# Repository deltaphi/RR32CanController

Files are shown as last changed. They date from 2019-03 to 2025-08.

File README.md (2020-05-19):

# RR32CanSwitchboard
Sketch for a Switchboard talking the Maerklin CAN protocol based on the ESP32 NodeMCU-Board.

## CI Status

* Linux Unittest Build


* Embedded Build


* Windows Unittest Build


## Software

This project is built using PlatformIO. It makes use of some features that may
not be easily portable to other Arduino-supported MCUs.

### Library Notes

This project makes use of several libraries. Versioned links to those libraries
are available as git submodules. Note that for seom libraries, using forks from
the same source as this project may be required.

Note that the CAN driver from the lib directory *must not* be present when you
want to compile using the ESP32-IDF driver. Otherwise, the Controller will just
attempt to sit there without sending queued messages or receiving any messages
transmitted on the bus.

### WiFi

This sketch only supports runtime-selection of CAN connection vs. WiFi
connection. The WiFi connection information (SSID, Password, IP of CAN-Gateway)
must be hardcoded.

To support hardcoding, a template file "_wificonfig.h" is provided. Copy the
template to "wificonfig.h" and adjust the configuration information to your
needs.

### Menuing

#### General concept

General: Shift + Direction Change enters the menu (cycles through menus) or leaves the menu without applying any changes.

Menu Levels:

* Level 0/Default: Loco Control
* Level 1: Loco List
* Level 2: Settings Menu

#### Menuing for Accessories

Menuing is required to map turnout input buttons to turnouts or action lists.

TODO: Design.

#### Menuing for Engine Control

Menuing is required for selecting an engine to control. This involves the following usecases:

* Select locally known engine
    * Show list of locally known Engines
    * Select engine
    * Selected Engine is now the active engine

* Select locally unknown engine
    * Verify that at least one local slot for an engine is open
    * If not:
        * Promt the user to remove an engine from the local database to be able to download a new one.
        * Show list of locally known Engines
        * Select an engine.
        * Selected Engine is marked for replacement
    * If yes:
        * Empty engine slot with lowest index is marked for replacement
    * Download list of Engines & total number of known engines from the master controller.
    * Either: Select engine from the master list
        * Details of Selected engine are downloaded.
    * Either: Scroll up/down beyond the currently known set of engine names.
        * If the engine name is unknown, download list of engines from the master controller.
    * Once the download is complete, the selected engine is now the active engine

#### Encoder Acceleration for Engine Control

Formula for acceleration curve: y = m*x + c. x is the time since the last rotation in the same direction,
y is the number of actual increments to apply.

The acceleration is linear. It should be set up so that there is a cutoff at 500ms (no acceleration when
increments are more than half a second apart) and that an "immediate" half rotation (e.g., within 50ms)
hits the opposite end of engine velocity.

Thus, boundary conditions for an encoder with 24 increments per rotaton are:
1 Tick = m*500ms + c
kMaxEngineVelocity Ticks / 12 increments = m * (50ms / 12 increments) + c

Formulas for calculating m and c:

m = (y1 - y2)/(x1 - x2) = (1 - (kMaxEngineVelocity/12))/(500 - (50/12)) = -0.16

c = y1 - m*x1 = 84.03

#### Settings Menu

Menu Entries:

* Turnout mapping
* Action list mapping
* Default connection settings
* WiFi settings

##### Turnout Mapping

When in the Turnout mapping menu:

* Press a button (red or green) for a turnout
* Display shows number of button and whether red or green was pressed (line 1)
* Display shows human-readable number of currently mapped turnout
* Use encoder to adjust the number of the turnout
* pressing the encoder stores the turnout mapping (visual feedback possible?)
* pressing another turnout button switches to settings for that button
* pressing shift + encoder leaves the menu.

Possible extension: Use the function buttons to increase/decrease in steps of 10

### Unit Testing

This project includes a CMake project.
The CMake project is purely used to run unit tests for some parts of the code on your development machine.
You do not need to deal with unit tests (or the CMake project) unless you want to actively develop the software.
To use the CMake project, create an out-of-tree build directoy (in-tree build will confuse the Automagic of PlatformIO).
Unit testing should be possible using any C++14 capable compiler on any Desktop Operating System.
It has been tested successefully using MSVC 2017 Community Edition.

## Hardware

### PCB

There is a KiCAD PCB design included for turning this project into a handheld device.
The PCB is designed for the [Strapubox 2090 case](https://www.reichelt.de/kunststoffgehaeuse-129-x-40-x-26-mm-sp-2090-sw-p33828.html?&trstct=pos_0).

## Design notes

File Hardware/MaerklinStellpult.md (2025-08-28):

# Abmessungen Maerklin Stellpult

## Grau

Katalogangabe: 40x80mm

## Blau

Gehäuse: 36,5mm x 70mm
Überstand Anschlüsse:
* Buchse Links 3,2mm
* Stift rechts 7,7mm
* Buchsen hinten 3,2mm

Größe über alles:
40 x 81,7mm

Mindestabstand der Gehäuse beim Stecken:
3,2mm + 1mm = 4,2mm - real nie erreicht!

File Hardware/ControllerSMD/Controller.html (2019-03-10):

# C:\Users\Damian\Documents\PlatformIO\Projects\esp32-can\Hardware\Controller\Controller.sch

09.03.2019 09:19:10

Eeschema (5.0.2)-1

Component Count:60

Ref | Qnty | Value | Part | Datasheet | Description | Vendor
C1, C2, C3, C4, C5, C6, C7, C8, C9, C10 | 10 | 10n | Device:C | ~ | Unpolarized capacitor
C11 | 1 | 100n | Device:C | ~ | Unpolarized capacitor
C12 | 1 | 470u | Device:CP | ~ | Polarized capacitor
C13 | 1 | 4u7 | Device:CP | ~ | Polarized capacitor
D1, D2, D3 | 3 | D_Schottky | Device:D_Schottky | ~ | Schottky diode
H1, H2 | 2 | Case Screw | Mechanical:MountingHole | ~ | Mounting Hole without connection
H3, H4, H5, H6 | 4 | PCB Screw | Mechanical:MountingHole_Pad | ~ | Mounting Hole with connection
J1 | 1 | 8P8C | Connector:8P8C | ~ | RJ connector, 8P8C (8 positions 8 connected), RJ31/RJ32/RJ33/RJ34/RJ35/RJ41/RJ45/RJ49/RJ61
J2 | 1 | LCD Header | Connector:Conn_01x04_Female | ~ | Generic connector, single row, 01x04, script generated (kicad-library-utils/schlib/autogen/connector/)
J3 | 1 | USB_B_Micro | Connector:USB_B_Micro | ~ | USB Micro Type B connector
J4 | 1 | S88 | Connector_Generic:Conn_01x06 | ~ | Generic connector, single row, 01x06, script generated (kicad-library-utils/schlib/autogen/connector/)
J5 | 1 | Screw_Terminal_01x05 | Connector:Screw_Terminal_01x05 | ~ | Generic screw terminal, single row, 01x05, script generated (kicad-library-utils/schlib/autogen/connector/)
R1, R2, R3, R4, R5, R6, R7, R8, R9, R10, R11, R12, R13, R14, R15, R16, R17, R18, R19, R20 | 20 | 10k | Device:R | ~ | Resistor
SW1 | 1 | Rotary_Encoder_Switch | Device:Rotary_Encoder_Switch | ~ | Rotary encoder, dual channel, incremental quadrate outputs, with switch
SW2 | 1 | SW_F0 | Switch:SW_Push | | Push button switch, generic, two pins
SW3 | 1 | SW_F1 | Switch:SW_Push | | Push button switch, generic, two pins
SW4 | 1 | SW_F2 | Switch:SW_Push | | Push button switch, generic, two pins
SW5 | 1 | SW_F3 | Switch:SW_Push | | Push button switch, generic, two pins
SW6 | 1 | SW_F4 | Switch:SW_Push | | Push button switch, generic, two pins
SW7 | 1 | Shift | Switch:SW_Push | | Push button switch, generic, two pins
SW8 | 1 | Stop | Switch:SW_Push | | Push button switch, generic, two pins
U1 | 1 | ESP32-WROOM-32 | RF_Module:ESP32-WROOM-32 | https://www.espressif.com/sites/default/files/documentation/esp32-wroom-32d_esp32-wroom-32u_datasheet_en.pdf | RF Module, ESP32-D0WDQ6 SoC, Wi-Fi 802.11b/g/n, Bluetooth, BLE, 32-bit, 2.7-3.6V, SMD
U2 | 1 | TJA1051T | Interface_CAN_LIN:TJA1051T | http://www.nxp.com/documents/data_sheet/TJA1051.pdf | High-Speed CAN Transceiver, silent mode, SOIC-8
U3 | 1 | 74LS367 | 74xx:74LS367 | http://www.ti.com/lit/gpn/sn74LS367 | Hex Bus Driver 3-state outputs
U4 | 1 | CH340C | Interface_USB:CH340G | http://www.datasheet5.com/pdf-local-2195953 | USB serial converter, UART, SOIC-16
U5 | 1 | XM1584 | ControllerParts:XM1584 | | XM1584 Switching Voltage Regulator Module

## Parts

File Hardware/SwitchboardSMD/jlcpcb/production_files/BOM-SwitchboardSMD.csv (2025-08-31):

Comment | Designator | Footprint | LCSC | Quantity
100k | R14,R15,R16,R17,R18,R19,R20,R21,R3 | R_1206_3216Metric_Pad1.30x1.75mm_HandSolder | C17900 | 9
10k | R1,R10,R11,R2,R4,R5,R6,R7,R8,R9 | R_1206_3216Metric_Pad1.30x1.75mm_HandSolder | C17902 | 10
10n | C1,C2,C3,C4,C5,C6,C7,C8 | C_1206_3216Metric | C1846 | 8
100n | C9 | C_1206_3216Metric | C24497 | 1
4014 | U3 | TSSOP-16_4.4x5mm_P0.65mm | C2877059 | 1
MMBT5551L | Q1 | SOT-23 | C41095 | 1
4044 | U1,U2 | TSSOP-16_4.4x5mm_P0.65mm | C74801 | 2
SW_Push | SW1 | SW_PUSH_6mm |  | 1
MountingHole_Pad | H1 | MountingHole_2.2mm_M2 |  | 1
MountingHole_Pad | H2 | MountingHole_2.2mm_M2 |  | 1
MountingHole_Pad | H3 | MountingHole_2.2mm_M2 |  | 1
MountingHole_Pad | H4 | MountingHole_2.2mm_M2 |  | 1
SW_Push | SW2 | SW_PUSH_6mm |  | 1
SW_Push | SW3 | SW_PUSH_6mm |  | 1
SW_Push | SW5 | SW_PUSH_6mm |  | 1
SW_Push | SW6 | SW_PUSH_6mm |  | 1
SW_Push | SW7 | SW_PUSH_6mm |  | 1
SW_Push | SW8 | SW_PUSH_6mm |  | 1
SW_Push | SW4 | SW_PUSH_6mm |  | 1
S88_In | J2 | PinSocket_1x06_P2.54mm_Horizontal |  | 1
S88_Out | J4 | PinHeader_1x06_P2.54mm_Horizontal |  | 1
MountingHole_Pad | H5 | MountingHole_3.2mm_M3_Pad_Via |  | 1

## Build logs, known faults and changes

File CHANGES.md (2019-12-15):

# ChangeLog

## Version 1.1

* Add serial console.
  * Switch turnouts not accessible via button.
  * Store and execute Accessory Action Lists.

## Version 1.0

This version is the first general-purpose release. Every release before this
was geared towards a specific prototypical setup.

* Support WiFi and CAN connection.
* Support configurable Turnouts.

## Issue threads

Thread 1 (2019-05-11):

RX/TX lines are swapped

deltaphi, 2019-05-11:
The RX and TX lines in the PCD design are swapped, at least in f3e92ce8fdfd0f38a7215b2d083cc8cbbf3de2ce

Correct is:

* TXD0/IO1/Pin 35 of the ESP32WROOM must be connected to RXD/Pin3 of the CH340C
* PXD0/IO3/Pin 34 of the ESP32WROOM must be connected to TXD/Pin2 of the CH340C

Closed 2019-05-19.

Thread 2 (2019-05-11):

Auto-Reset circuit not working

deltaphi, 2019-05-11:
The Auto-Reset Circuit itself is working. However:

* There should be 10k pullups on GPIO0 an EN.
* The Auto-Reset Circuit does not guard against serial software asserting both RTS and DTR.

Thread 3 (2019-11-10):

Acceleration values questionable

deltaphi, 2019-11-10:
The computed acceleration values do not appear to be correct. Also, the acceleration is somewhat unintuitive, as the uC appears to be loosing encoder ticks on very fast rotations.

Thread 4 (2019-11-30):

All turnouts switched on startup

deltaphi, 2019-11-30:
When the ESP32 is starting, it immediately generates button presses for all turnouts.

Reason is likely the inverted logic of the S88 bus.

Closed 2019-11-30.

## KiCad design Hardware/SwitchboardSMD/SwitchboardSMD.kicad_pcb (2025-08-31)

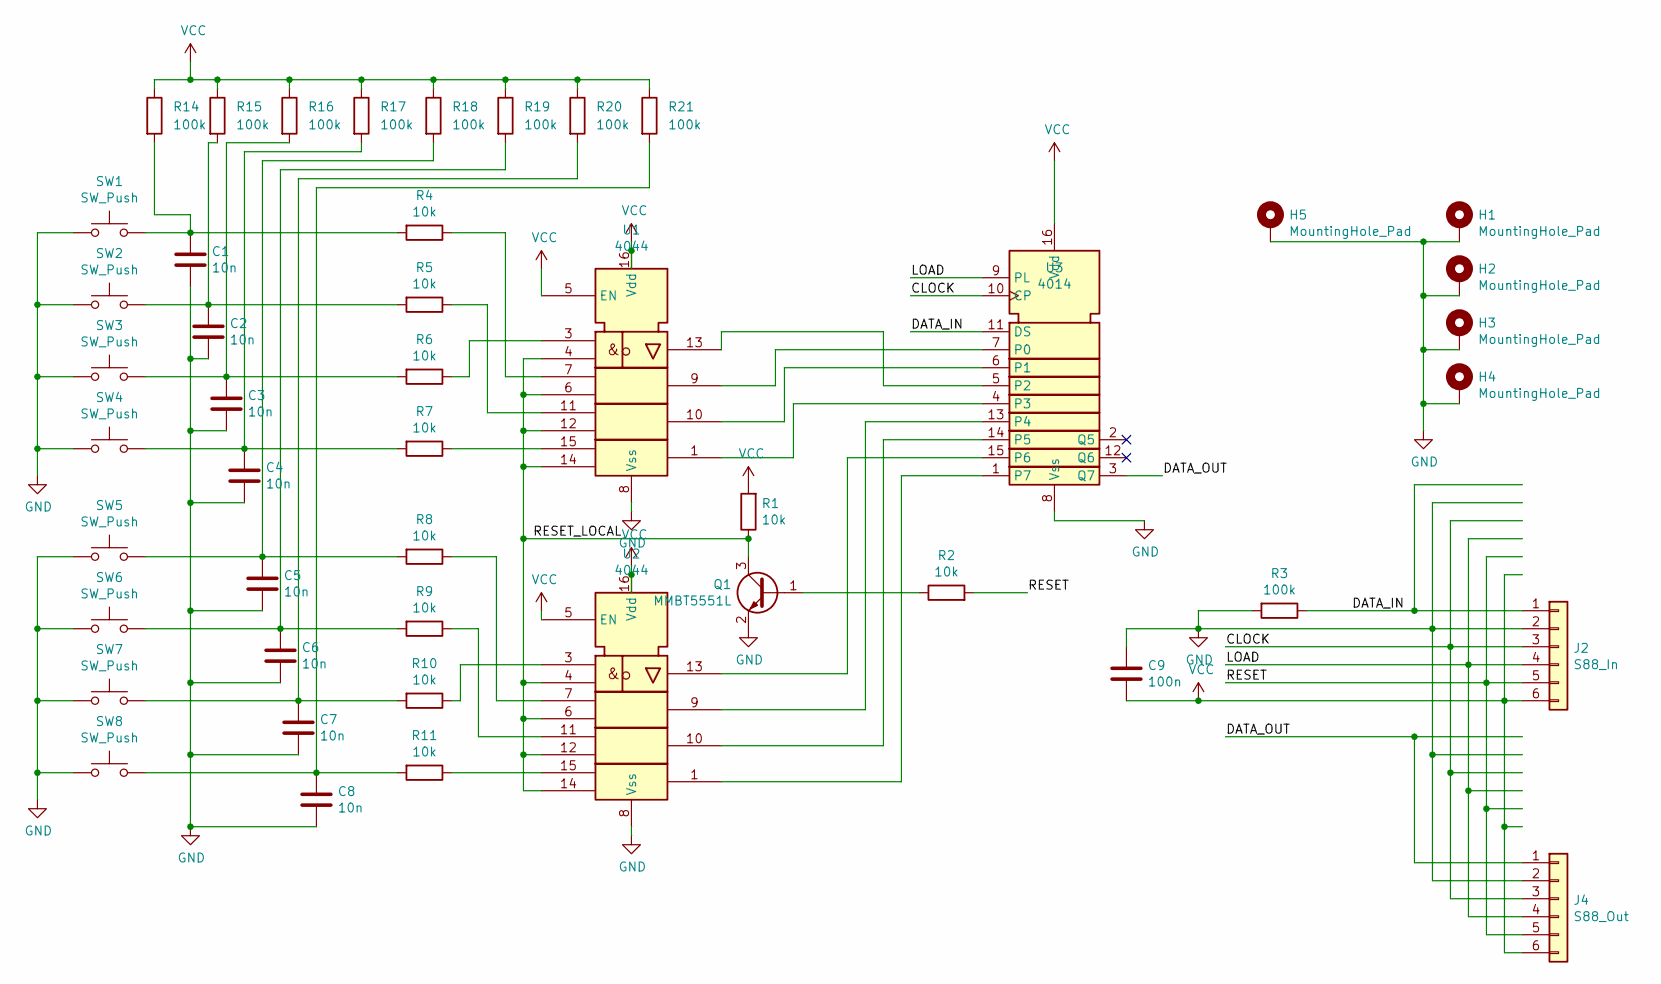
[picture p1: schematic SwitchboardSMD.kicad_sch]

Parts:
C1, C2, C3, C4, C5, C6, C7, C8: 10n; C_1206_3216Metric
C9: 100n; C_1206_3216Metric
H1, H2, H3, H4: MountingHole_Pad; MountingHole_2.2mm_M2
H5: MountingHole_Pad; MountingHole_3.2mm_M3_Pad_Via
J2: S88_In; PinSocket_1x06_P2.54mm_Horizontal
J4: S88_Out; PinHeader_1x06_P2.54mm_Horizontal
Q1: MMBT5551L; SOT-23
R1, R2, R4, R5, R6, R7, R8, R9, R10, R11: 10k; R_1206_3216Metric_Pad1.30x1.75mm_HandSolder
R3, R14, R15, R16, R17, R18, R19, R20, R21: 100k; R_1206_3216Metric_Pad1.30x1.75mm_HandSolder
SW1, SW2, SW3, SW4, SW5, SW6, SW7, SW8: SW_Push; SW_PUSH_6mm
U1, U2: 4044; TSSOP-16_4.4x5mm_P0.65mm
U3: 4014; TSSOP-16_4.4x5mm_P0.65mm

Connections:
/CLOCK: J2.3, J4.3, U3.10 (CP)
/DATA_IN: J2.1, R3.1, U3.11 (DS)
/DATA_OUT: J4.1, U3.3 (Q7)
/LOAD: J2.4, J4.4, U3.9 (PL)
/RESET: J2.5, J4.5, R2.2
/RESET_LOCAL: Q1.3 (C), R1.1, U1.4, U1.6, U1.12, U1.14, U2.4, U2.6, U2.12, U2.14
GND: C1.2, C2.2, C3.2, C4.2, C5.2, C6.2, C7.2, C8.2, C9.1, H1.1, H2.1, H3.1, H4.1, H5.1, J2.2, J4.2, Q1.2 (E), R3.2, SW1.1, SW2.1, SW3.1, SW4.1, SW5.1, SW6.1, SW7.1, SW8.1, U1.8 (Vss), U2.8 (Vss), U3.8 (Vss)
unnamed: C1.1, R4.2, R14.2, SW1.2
unnamed: C2.1, R5.2, R15.2, SW2.2
unnamed: C3.1, R6.2, R16.2, SW3.2
unnamed: C4.1, R7.2, R17.2, SW4.2
unnamed: C5.1, R8.2, R18.2, SW5.2
unnamed: C6.1, R9.2, R19.2, SW6.2
unnamed: C7.1, R10.2, R20.2, SW7.2
unnamed: C8.1, R11.2, R21.2, SW8.2
unnamed: Q1.1 (B), R2.1
unnamed: R4.1, U1.7
unnamed: R5.1, U1.11
unnamed: R6.1, U1.3
unnamed: R7.1, U1.15
unnamed: R8.1, U2.7
unnamed: R9.1, U2.11
unnamed: R10.1, U2.3
unnamed: R11.1, U2.15
unnamed: U1.9, U3.7 (P0)
unnamed: U1.10, U3.6 (P1)
unnamed: U1.13, U3.5 (P2)
unnamed: U1.1, U3.4 (P3)
unnamed: U2.9, U3.13 (P4)
unnamed: U2.10, U3.14 (P5)
unnamed: U2.13, U3.15 (P6)
unnamed: U2.1, U3.1 (P7)
VCC: C9.2, J2.6, J4.6, R1.2, R14.1, R15.1, R16.1, R17.1, R18.1, R19.1, R20.1, R21.1, U1.5 (EN), U1.16 (Vdd), U2.5 (EN), U2.16 (Vdd), U3.16 (Vdd)

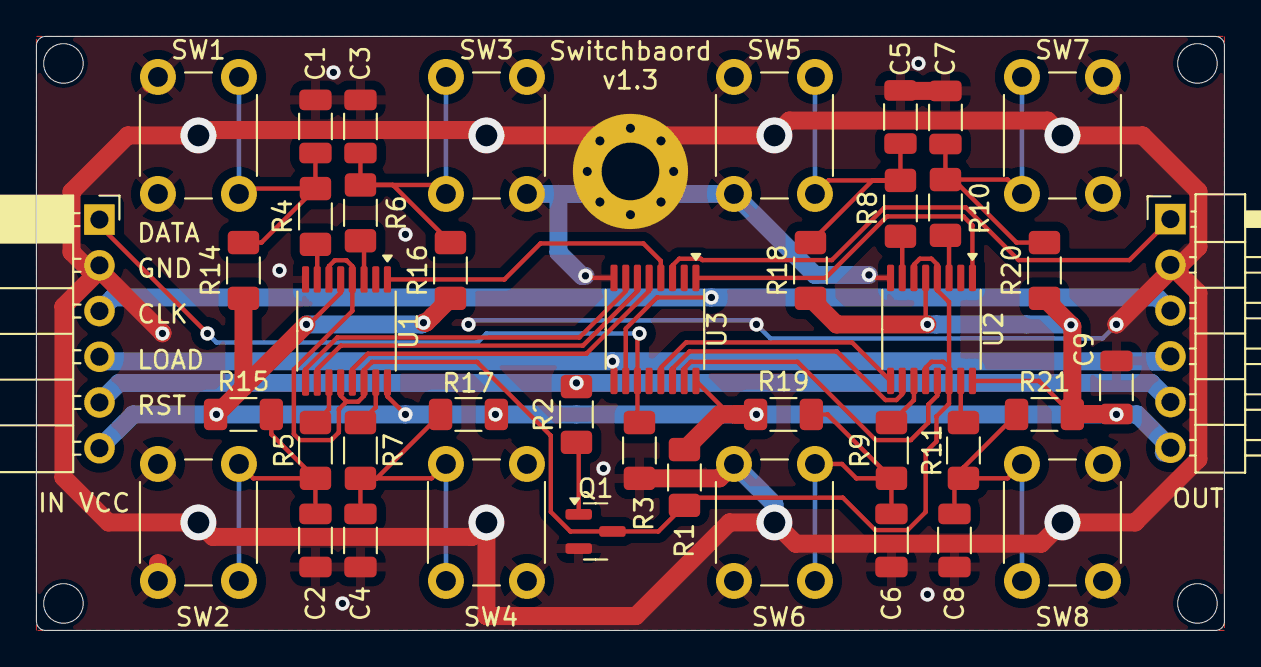
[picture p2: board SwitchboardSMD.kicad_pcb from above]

Board: 2 copper layers, 66.0 x 33.0 mm, 47 parts (0 on the bottom side), 33 nets.

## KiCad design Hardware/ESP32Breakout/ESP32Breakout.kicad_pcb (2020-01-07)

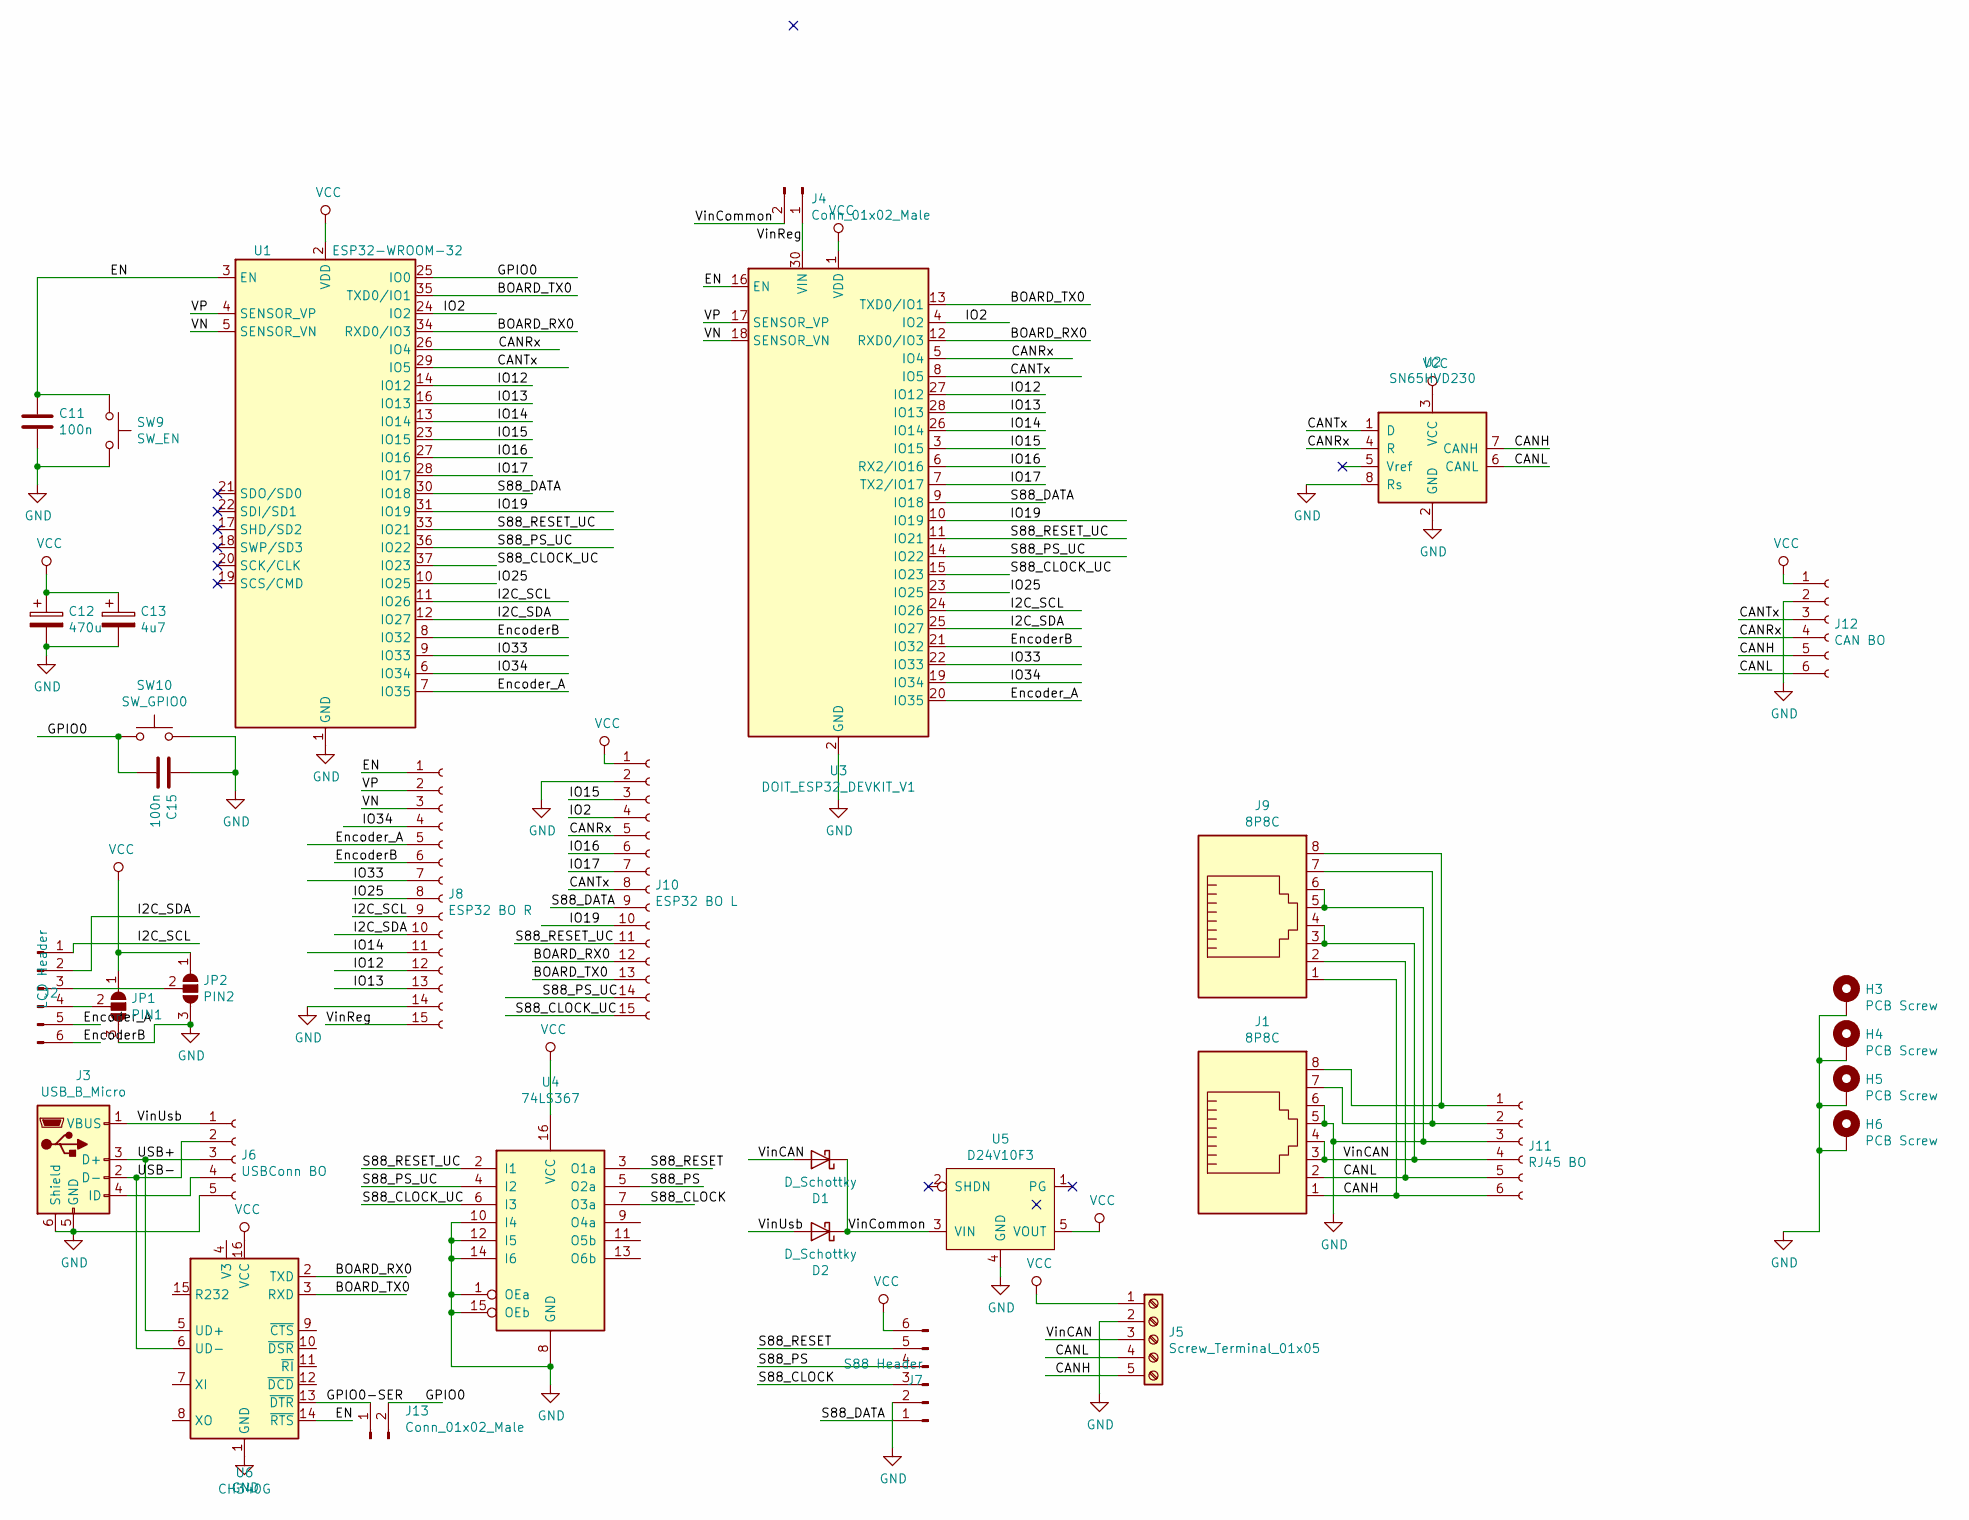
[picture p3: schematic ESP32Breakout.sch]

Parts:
C11, C15: 100n; C_Disc_D3.4mm_W2.1mm_P2.50mm
C12: 470u; CP_Radial_D10.0mm_P5.00mm
C13: 4u7; CP_Radial_D5.0mm_P2.50mm
D1, D2: D_Schottky; D_A-405_P7.62mm_Horizontal
H3, H4, H5, H6: PCB Screw; MountingHole_3.2mm_M3_Pad_Via
J1, J9: 8P8C; RJ45_Amphenol_54602-x08_Horizontal
J2: LCD Header; PinHeader_1x06_P2.54mm_Vertical
J3: USB_B_Micro; USB_Micro-B_Molex_47346-0001
J4, J13: Conn_01x02_Male; PinHeader_1x02_P2.54mm_Vertical
J5: Screw_Terminal_01x05; TerminalBlock_4Ucon_1x05_P3.50mm_Vertical
J6: USBConn BO; PinHeader_1x05_P2.54mm_Vertical
J7: S88 Header; PinHeader_1x06_P2.54mm_Vertical
J8: ESP32 BO R; PinHeader_1x15_P2.54mm_Vertical
J10: ESP32 BO L; PinHeader_1x15_P2.54mm_Vertical
J11: RJ45 BO; PinHeader_1x06_P2.54mm_Vertical
J12: CAN BO; PinHeader_1x06_P2.54mm_Vertical
JP1: PIN1; SolderJumper-3_P1.3mm_Open_Pad1.0x1.5mm_NumberLabels
JP2: PIN2; SolderJumper-3_P1.3mm_Open_Pad1.0x1.5mm_NumberLabels
SW9: SW_EN; SW_PUSH_6mm
SW10: SW_GPIO0; SW_PUSH_6mm
U1: ESP32-WROOM-32
U2: SN65HVD230; SOIC-8_3.9x4.9mm_P1.27mm
U3: DOIT_ESP32_DEVKIT_V1; ESP32-DEVKITV1
U4: 74LS367; SOP-16_4.55x10.3mm_P1.27mm
U5: D24V10F3
U6: CH340G; SOIC-16_3.9x9.9mm_P1.27mm

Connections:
/BOARD_RX0: J10.12, U1.34 (RXD0/IO3), U3.12 (RXD0/IO3), U6.2 (TXD)
/BOARD_TX0: J10.13, U1.35 (TXD0/IO1), U3.13 (TXD0/IO1), U6.3 (RXD)
/CANH: J1.1, J5.5, J9.1, J11.6, J12.5, U2.7 (CANH)
/CANL: J1.2, J5.4, J9.2, J11.5, J12.6, U2.6 (CANL)
/CANRx: J10.5, J12.4, U1.26 (IO4), U2.4 (R), U3.5 (IO4)
/CANTx: J10.8, J12.3, U1.29 (IO5), U2.1 (D), U3.8 (IO5)
/EN: C11.1, J8.1, SW9.1, U1.3 (EN), U3.16 (EN), U6.14 (~RTS)
/EncoderB: J2.6, J8.6, U1.8 (IO32), U3.21 (IO32)
/Encoder_A: J2.5, J8.5, U1.7 (IO35), U3.20 (IO35)
/GPIO0: C15.2, J13.2, SW10.1, U1.25 (IO0)
/GPIO0-SER: J13.1, U6.13 (~DTR)
/I2C_SCL: J2.1, J8.9, U1.11 (IO26), U3.24 (IO26)
/I2C_SDA: J2.2, J8.10, U1.12 (IO27), U3.25 (IO27)
/IO2: J10.4, U1.24 (IO2), U3.4 (IO2)
/IO12: J8.12, U1.14 (IO12), U3.27 (IO12)
/IO13: J8.13, U1.16 (IO13), U3.28 (IO13)
/IO14: J8.11, U1.13 (IO14), U3.26 (IO14)
/IO15: J10.3, U1.23 (IO15), U3.3 (IO15)
/IO16: J10.6, U1.27 (IO16), U3.6 (RX2/IO16)
/IO17: J10.7, U1.28 (IO17), U3.7 (TX2/IO17)
/IO19: J10.10, U1.31 (IO19), U3.10 (IO19)
/IO25: J8.8, U1.10 (IO25), U3.23 (IO25)
/IO33: J8.7, U1.9 (IO33), U3.22 (IO33)
/IO34: J8.4, U1.6 (IO34), U3.19 (IO34)
/S88_CLOCK: J7.3, U4.7 (O3a)
/S88_CLOCK_UC: J10.15, U1.37 (IO23), U3.15 (IO23), U4.6 (I3)
/S88_DATA: J7.1, J10.9, U1.30 (IO18), U3.9 (IO18)
/S88_PS: J7.4, U4.5 (O2a)
/S88_PS_UC: J10.14, U1.36 (IO22), U3.14 (IO22), U4.4 (I2)
/S88_RESET: J7.5, U4.3 (O1a)
/S88_RESET_UC: J10.11, U1.33 (IO21), U3.11 (IO21), U4.2 (I1)
/USB+: J3.3 (D+), J6.3, U6.5 (UD+)
/USB-: J3.2 (D-), J6.2, U6.6 (UD-)
/VN: J8.3, U1.5 (SENSOR_VN), U3.18 (SENSOR_VN)
/VP: J8.2, U1.4 (SENSOR_VP), U3.17 (SENSOR_VP)
/VinCAN: D1.2 (A), J1.3, J1.4, J5.3, J9.3, J9.4, J11.4
/VinCommon: D1.1 (K), D2.1 (K), J4.2, U5.3 (VIN)
/VinReg: J4.1, J8.15, U3.30 (VIN)
/VinUsb: D2.2 (A), J3.1 (VBUS), J6.1
GND: C11.2, C12.2, C13.2, C15.1, H3.1, H4.1, H5.1, H6.1, J1.5, J1.6, J3.5 (GND), J3.6 (Shield), J5.2, J6.5, J7.2, J8.14, J9.5, J9.6, J10.2, J11.3, J12.2, JP1.3 (B), JP2.3 (B), SW9.2, SW10.2, U1.1 (GND), U1.15 (GND), U1.38 (GND), U2.2 (GND), U2.8 (Rs), U3.2 (GND), U3.29 (GND), U4.1 (OEa), U4.8 (GND), U4.10 (I4), U4.12 (I5), U4.14 (I6), U4.15 (OEb), U5.4 (GND), U6.1 (GND)
unnamed: J1.7, J9.7, J11.2
unnamed: J1.8, J9.8, J11.1
unnamed: J2.3, JP2.2 (C)
unnamed: J2.4, JP1.2 (C)
unnamed: J3.4 (ID), J6.4
VCC: C12.1, C13.1, J5.1, J7.6, J10.1, J12.1, JP1.1 (A), JP2.1 (A), U1.2 (VDD), U2.3 (VCC), U3.1 (VDD), U4.16 (VCC), U5.5 (VOUT), U6.16 (VCC)

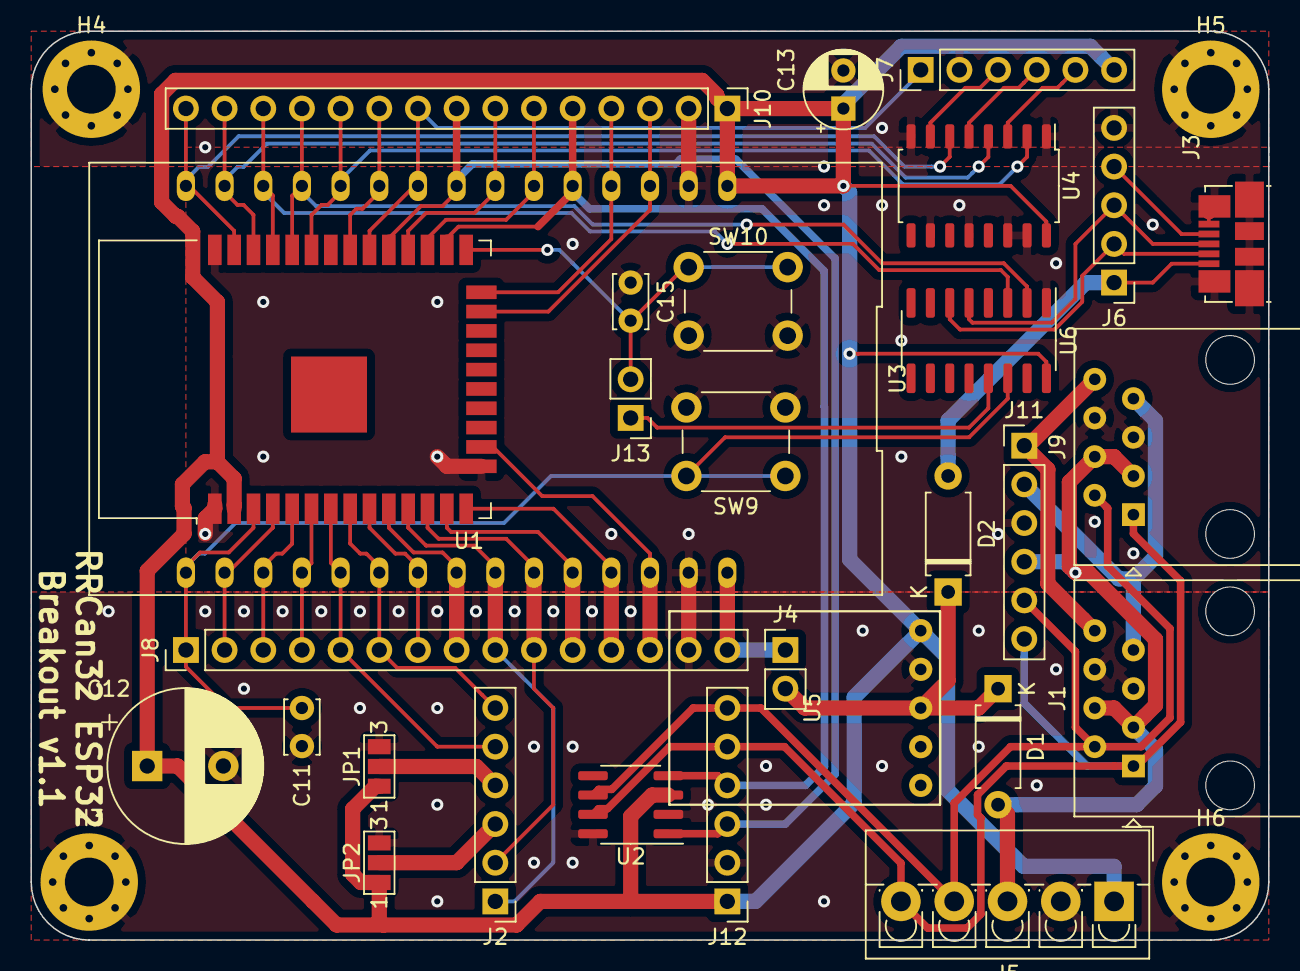
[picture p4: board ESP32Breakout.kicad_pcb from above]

Board: 2 copper layers, 81.3 x 59.7 mm, 33 parts (0 on the bottom side), 46 nets.

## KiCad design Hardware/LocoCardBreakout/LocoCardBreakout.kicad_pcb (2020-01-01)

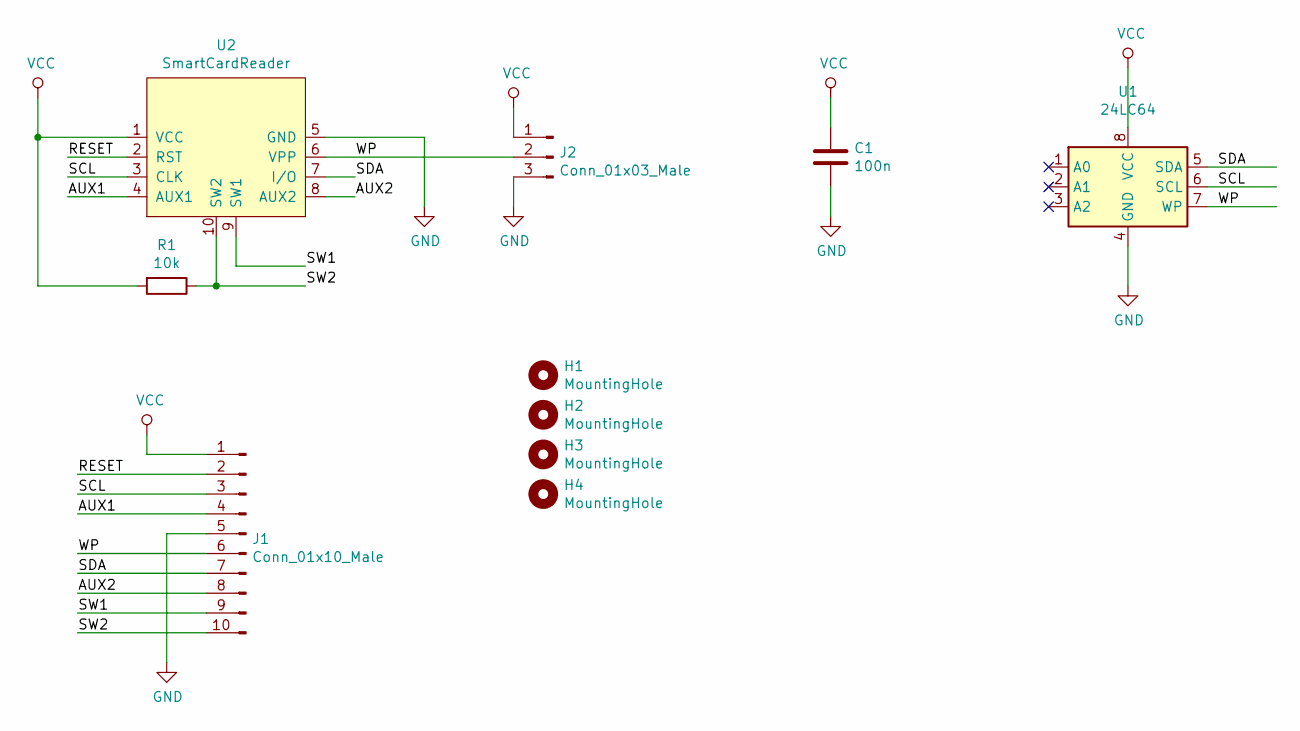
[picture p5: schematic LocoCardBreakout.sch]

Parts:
C1: 100n; C_Disc_D3.0mm_W1.6mm_P2.50mm
H1, H2, H3, H4: MountingHole; MountingHole_2.5mm
J1: Conn_01x10_Male; PinHeader_1x10_P2.54mm_Vertical
J2: Conn_01x03_Male; PinHeader_1x03_P2.54mm_Vertical
R1: 10k; R_Axial_DIN0207_L6.3mm_D2.5mm_P7.62mm_Horizontal
U1: 24LC64; DIP-8_W7.62mm_LongPads
U2: SmartCardReader

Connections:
/AUX1: J1.4, U2.4 (AUX1)
/AUX2: J1.8, U2.8 (AUX2)
/RESET: J1.2, U2.2 (RST)
/SCL: J1.3, U1.6 (SCL), U2.3 (CLK)
/SDA: J1.7, U1.5 (SDA), U2.7 (I/O)
/SW1: J1.9, U2.9 (SW1)
/SW2: J1.10, R1.1, U2.10 (SW2)
/WP: J1.6, J2.2, U1.7 (WP), U2.6 (VPP)
GND: C1.2, J1.5, J2.3, U1.4 (GND), U2.5 (GND)
VCC: C1.1, J1.1, J2.1, R1.2, U1.8 (VCC), U2.1 (VCC)

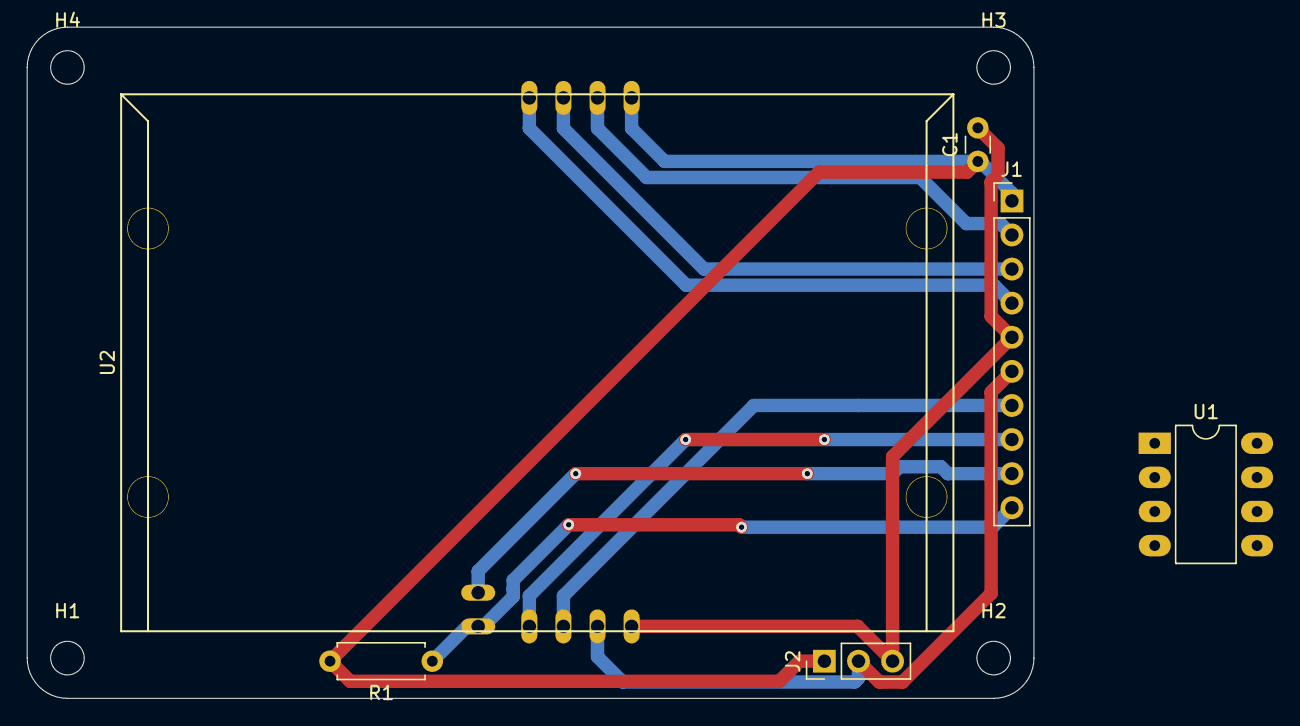
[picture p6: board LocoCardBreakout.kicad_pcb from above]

Board: 2 copper layers, 75.0 x 50.0 mm, 10 parts (0 on the bottom side), 10 nets.

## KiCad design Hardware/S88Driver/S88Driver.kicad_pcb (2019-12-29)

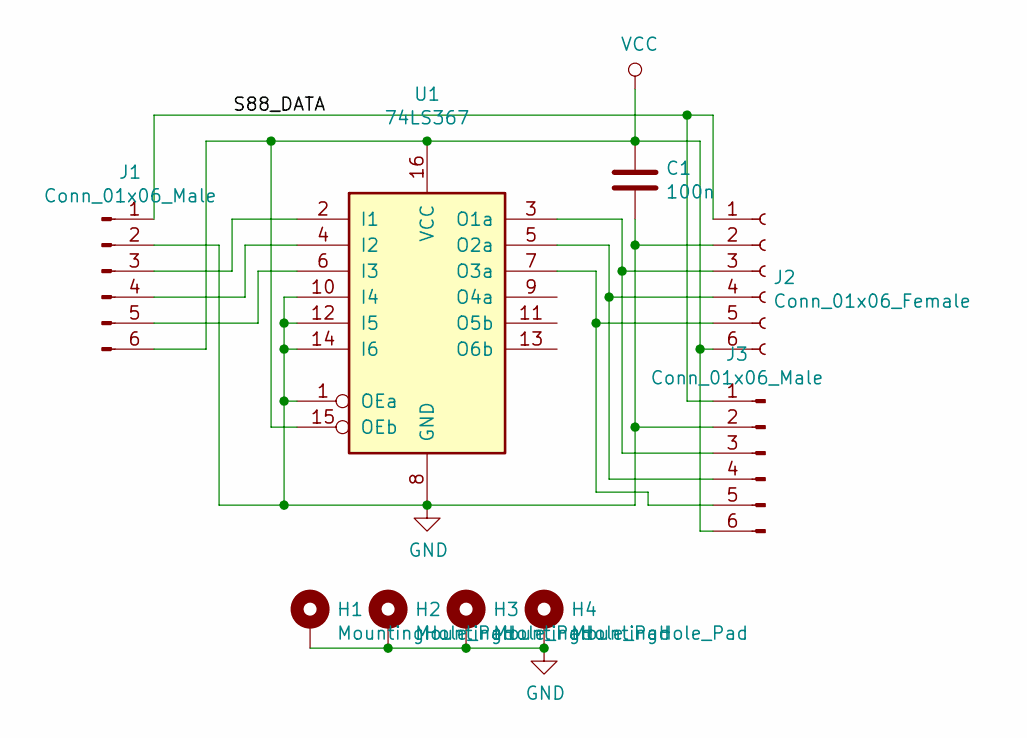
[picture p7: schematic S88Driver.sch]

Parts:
C1: 100n; C_Disc_D3.0mm_W1.6mm_P2.50mm
H1, H2, H3, H4: MountingHole_Pad; MountingHole_2.7mm_M2.5_Pad_Via
J1, J3: Conn_01x06_Male; PinSocket_1x06_P2.54mm_Vertical
J2: Conn_01x06_Female; PinSocket_1x06_P2.54mm_Horizontal
U1: 74LS367; DIP-16_W7.62mm_LongPads

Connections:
/S88_DATA: J1.1, J2.1, J3.1
GND: C1.2, H1.1, H2.1, H3.1, H4.1, J1.2, J2.2, J3.2, U1.1 (OEa), U1.8 (GND), U1.10 (I4), U1.12 (I5), U1.14 (I6)
unnamed: J1.3, U1.2 (I1)
unnamed: J1.4, U1.4 (I2)
unnamed: J1.5, U1.6 (I3)
unnamed: J2.3, J3.3, U1.3 (O1a)
unnamed: J2.4, J3.4, U1.5 (O2a)
unnamed: J2.5, J3.5, U1.7 (O3a)
VCC: C1.1, J1.6, J2.6, J3.6, U1.15 (OEb), U1.16 (VCC)

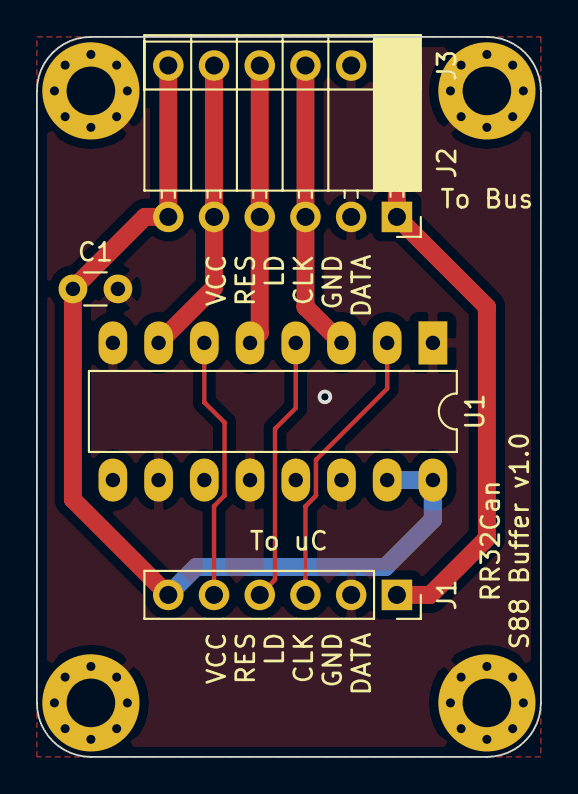
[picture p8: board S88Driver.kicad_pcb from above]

Board: 2 copper layers, 28.0 x 40.0 mm, 9 parts (0 on the bottom side), 9 nets.

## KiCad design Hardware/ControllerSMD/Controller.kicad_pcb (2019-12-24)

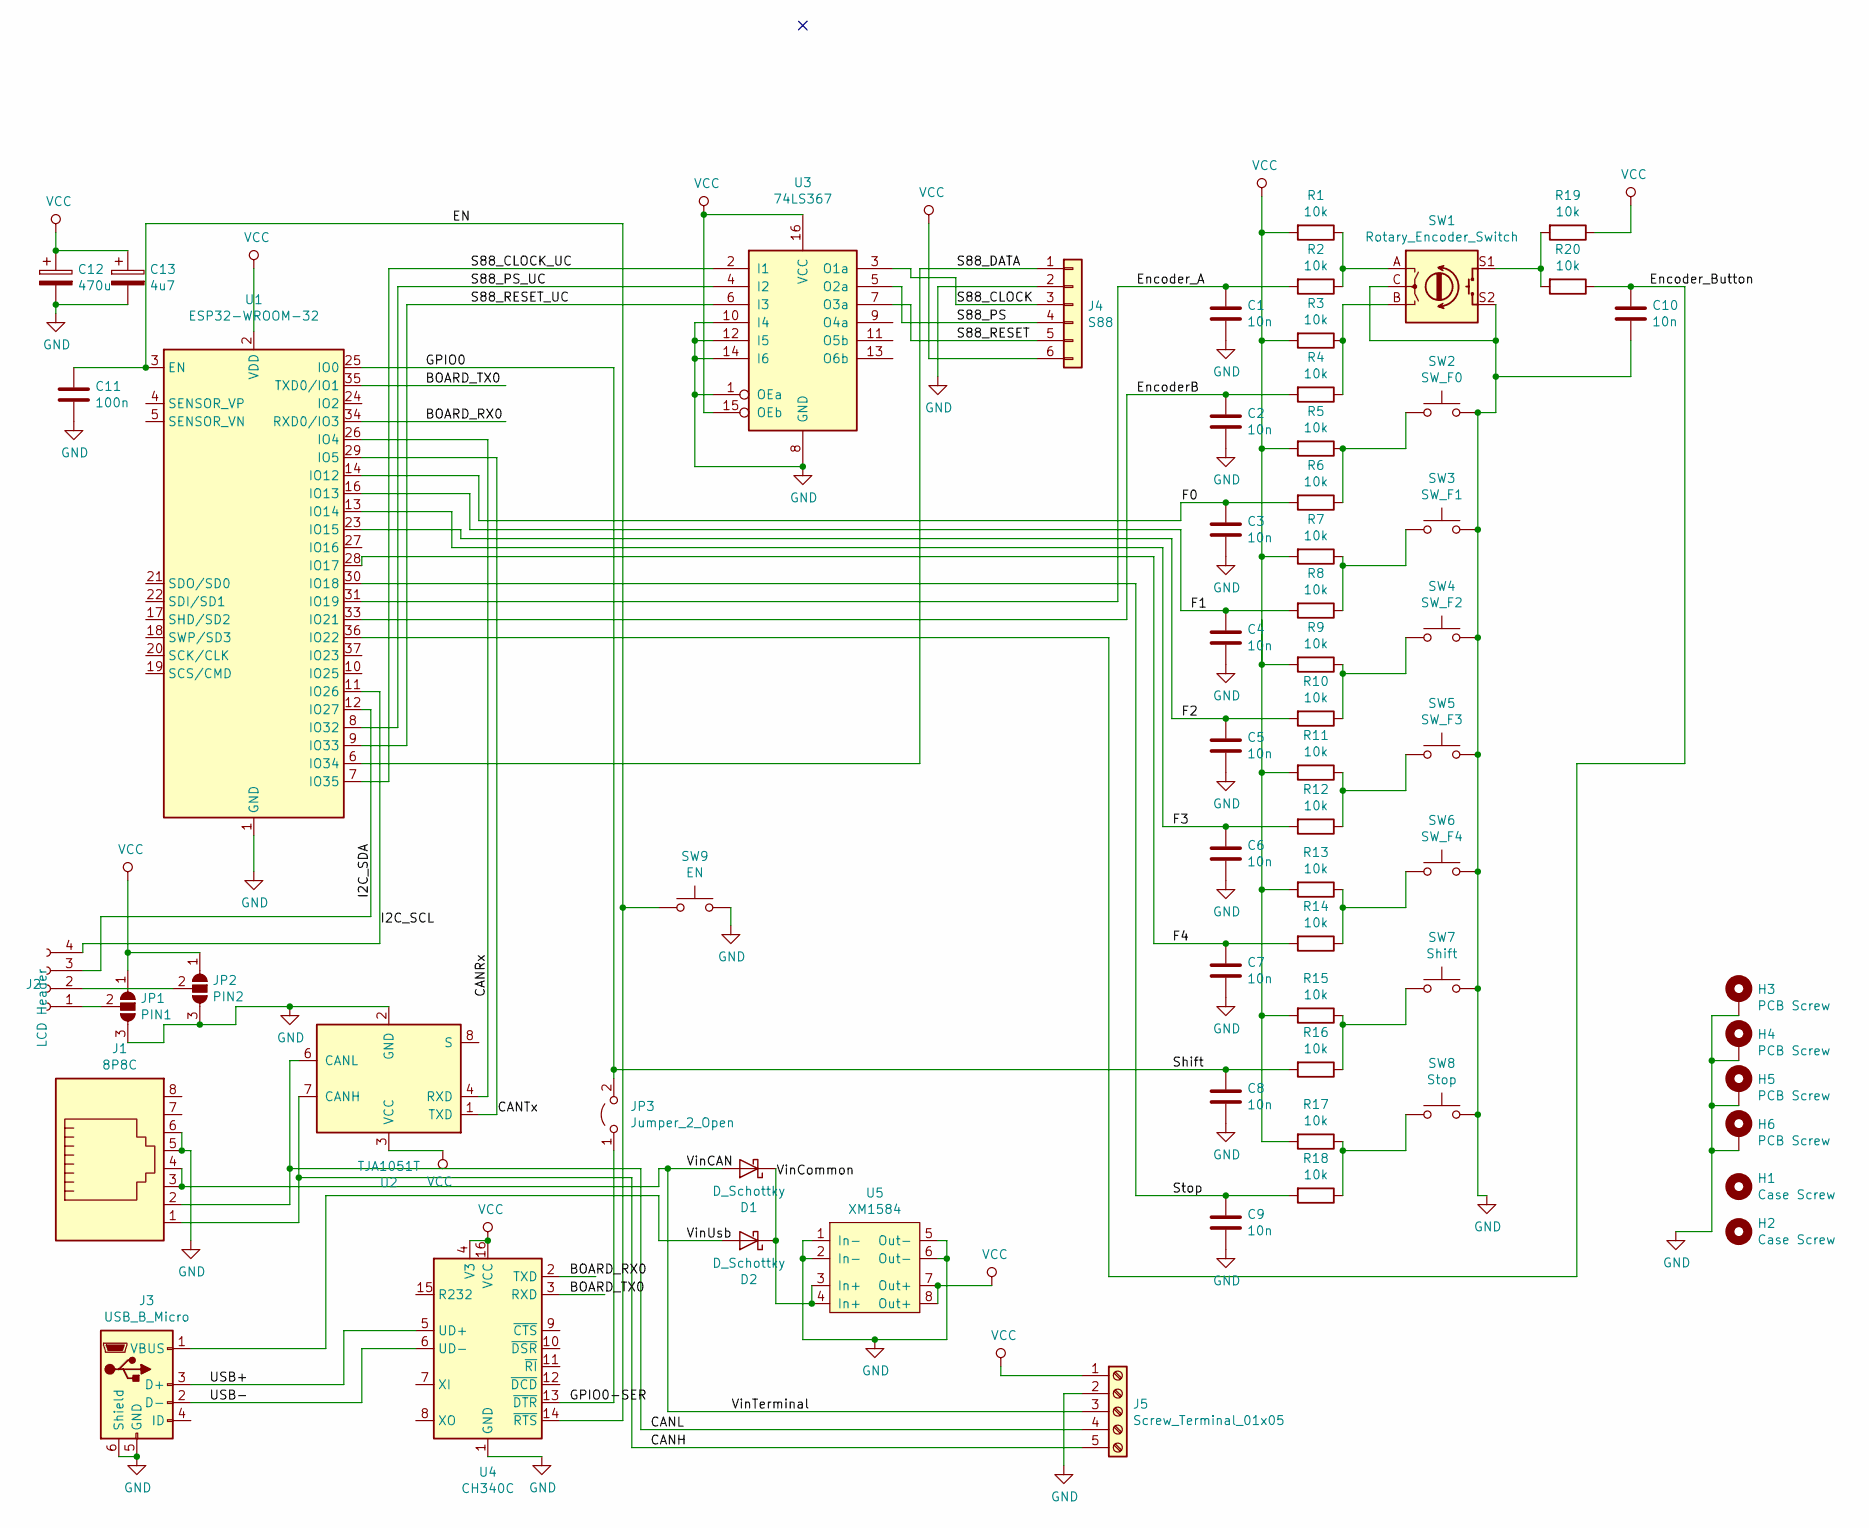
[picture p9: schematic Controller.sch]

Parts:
C1, C2, C3, C4, C5, C6, C7, C8, C9, C10: 10n; C_0805_2012Metric_Pad1.15x1.40mm_HandSolder
C11: 100n; C_0805_2012Metric_Pad1.15x1.40mm_HandSolder
C12: 470u; CP_Elec_6.3x7.7
C13: 4u7; CP_EIA-3216-18_Kemet-A_Pad1.58x1.35mm_HandSolder
D1, D2: D_Schottky; D_0603_1608Metric_Pad1.05x0.95mm_HandSolder
H1, H2: Case Screw; MountingHole_5.3mm_M5
H3, H4, H5, H6: PCB Screw; MountingHole_2.7mm_M2.5_Pad_Via
J1: 8P8C; RJ45_Amphenol_54602-x08_Horizontal
J2: LCD Header; PinHeader_1x04_P2.54mm_Vertical
J3: USB_B_Micro; USB_Micro-B_Molex_47346-0001
J4: S88; PinHeader_1x06_P2.54mm_Horizontal
J5: Screw_Terminal_01x05; TerminalBlock_4Ucon_1x05_P3.50mm_Vertical
JP1: PIN1; SolderJumper-3_P1.3mm_Open_Pad1.0x1.5mm_NumberLabels
JP2: PIN2; SolderJumper-3_P1.3mm_Open_Pad1.0x1.5mm_NumberLabels
JP3: Jumper_2_Open; SolderJumper-2_P1.3mm_Open_Pad1.0x1.5mm
R1, R2, R3, R4, R5, R6, R7, R8, R9, R10, R11, R12, R13, R14, R15, R16, R17, R18, R19, R20: 10k; R_0603_1608Metric_Pad1.05x0.95mm_HandSolder
SW1: Rotary_Encoder_Switch; RotaryEncoder_Alps_EC11E-Switch_Vertical_H20mm
SW2: SW_F0; SW_SPST_B3S-1000
SW3: SW_F1; SW_SPST_B3S-1000
SW4: SW_F2; SW_SPST_B3S-1000
SW5: SW_F3; SW_SPST_B3S-1000
SW6: SW_F4; SW_SPST_B3S-1000
SW7: Shift; SW_SPST_B3S-1000
SW8: Stop; SW_SPST_B3S-1000
SW9: EN; SW_Push_1P1T_NO_CK_KMR2
U1: ESP32-WROOM-32
U2: TJA1051T; SOIC-8_3.9x4.9mm_P1.27mm
U3: 74LS367; SOP-16_4.4x10.4mm_P1.27mm
U4: CH340C; SOIC-16_3.9x9.9mm_P1.27mm
U5: XM1584

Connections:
/BOARD_RX0: U1.34 (RXD0/IO3), U4.2 (TXD)
/BOARD_TX0: U1.35 (TXD0/IO1), U4.3 (RXD)
/CANH: J1.1, J5.5, U2.7 (CANH)
/CANL: J1.2, J5.4, U2.6 (CANL)
/CANRx: U1.26 (IO4), U2.4 (RXD)
/CANTx: U1.29 (IO5), U2.1 (TXD)
/EN: C11.1, SW9.1, U1.3 (EN), U4.14 (~RTS)
/EncoderB: C2.2, R4.2, U1.33 (IO21)
/Encoder_A: C1.2, R2.2, U1.31 (IO19)
/Encoder_Button: C10.2, R20.1, U1.36 (IO22)
/F0: C3.2, R6.2, U1.14 (IO12)
/F1: C4.2, R8.2, U1.16 (IO13)
/F2: C5.2, R10.2, U1.23 (IO15)
/F3: C6.2, R12.2, U1.13 (IO14)
/F4: C7.2, R14.2, U1.28 (IO17)
/GPIO0: C8.2, JP3.2 (B), R16.2, U1.25 (IO0)
/GPIO0-SER: JP3.1 (A), U4.13 (~DTR)
/I2C_SCL: J2.4, U1.11 (IO26)
/I2C_SDA: J2.3, U1.12 (IO27)
/S88_CLOCK: J4.3, U3.3 (O1a)
/S88_CLOCK_UC: U1.7 (IO35), U3.2 (I1)
/S88_DATA: J4.1, U1.6 (IO34)
/S88_PS: J4.4, U3.5 (O2a)
/S88_PS_UC: U1.8 (IO32), U3.4 (I2)
/S88_RESET: J4.5, U3.7 (O3a)
/S88_RESET_UC: U1.9 (IO33), U3.6 (I3)
/Stop: C9.2, R18.2, U1.30 (IO18)
/USB+: J3.3 (D+), U4.5 (UD+)
/USB-: J3.2 (D-), U4.6 (UD-)
/VinCAN: D1.2 (A), J1.3, J1.4, J5.3
/VinCommon: D1.1 (K), D2.1 (K), U5.3 (In+), U5.4 (In+)
/VinUsb: D2.2 (A), J3.1 (VBUS)
GND: C1.1, C2.1, C3.1, C4.1, C5.1, C6.1, C7.1, C8.1, C9.1, C10.1, C11.2, C12.2, C13.2, H3.1, H4.1, H5.1, H6.1, J1.5, J1.6, J3.5 (GND), J3.6 (Shield), J4.2, J5.2, JP1.3 (B), JP2.3 (B), SW1.C, SW1.S2, SW2.2, SW3.2, SW4.2, SW5.2, SW6.2, SW7.2, SW8.2, SW9.2, U1.1 (GND), U1.15 (GND), U1.38 (GND), U2.2 (GND), U3.1 (OEa), U3.8 (GND), U3.10 (I4), U3.12 (I5), U3.14 (I6), U4.1 (GND), U5.1 (In-), U5.2 (In-), U5.5 (Out-), U5.6 (Out-)
unnamed: J2.1, JP1.2 (C)
unnamed: J2.2, JP2.2 (C)
unnamed: R1.1, R2.1, SW1.A
unnamed: R3.1, R4.1, SW1.B
unnamed: R5.1, R6.1, SW2.1
unnamed: R7.1, R8.1, SW3.1
unnamed: R9.1, R10.1, SW4.1
unnamed: R11.1, R12.1, SW5.1
unnamed: R13.1, R14.1, SW6.1
unnamed: R15.1, R16.1, SW7.1
unnamed: R17.1, R18.1, SW8.1
unnamed: R19.2, R20.2, SW1.S1
VCC: C12.1, C13.1, J4.6, J5.1, JP1.1 (A), JP2.1 (A), R1.2, R3.2, R5.2, R7.2, R9.2, R11.2, R13.2, R15.2, R17.2, R19.1, U1.2 (VDD), U2.3 (VCC), U3.15 (OEb), U3.16 (VCC), U4.4 (V3), U4.16 (VCC), U5.7 (Out+), U5.8 (Out+)

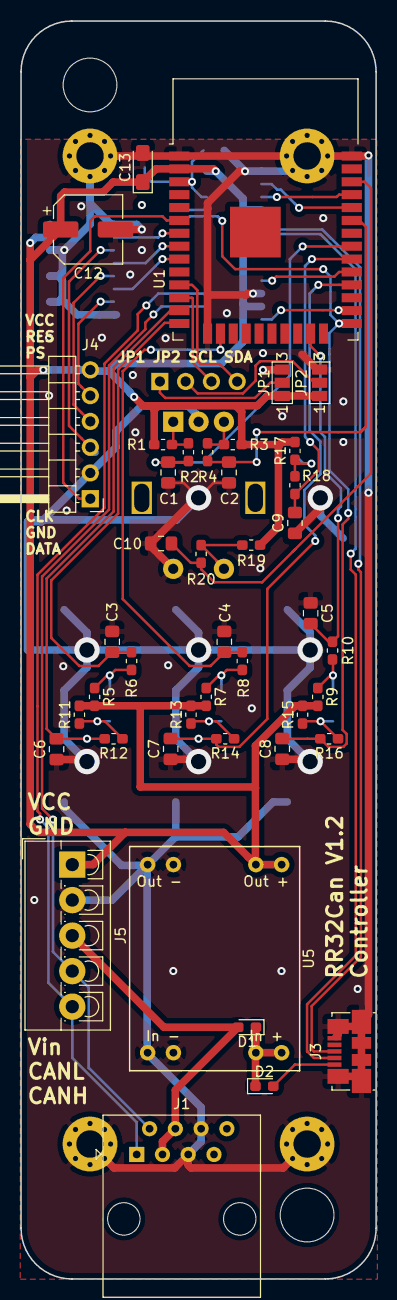
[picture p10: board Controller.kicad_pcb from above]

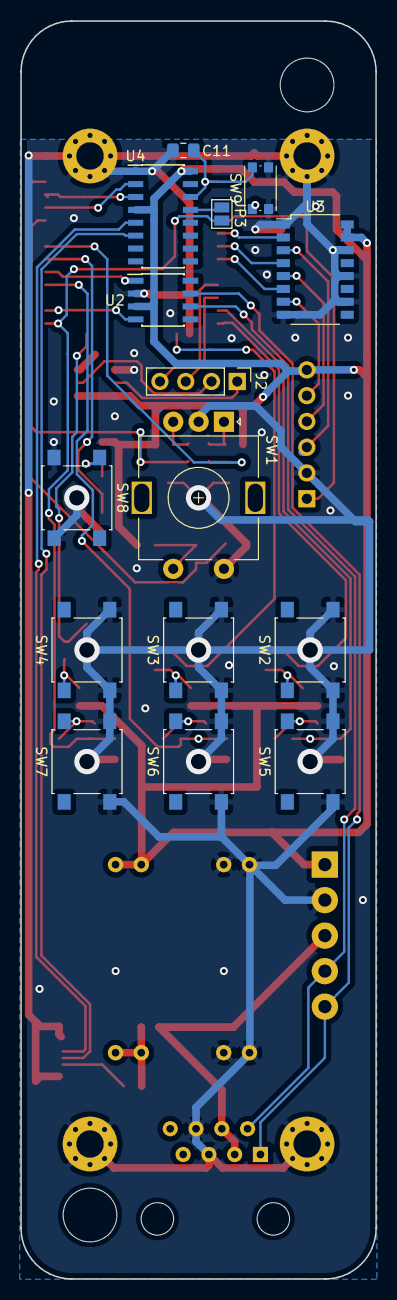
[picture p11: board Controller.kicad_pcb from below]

Board: 2 copper layers, 35.0 x 124.0 mm, 63 parts (15 on the bottom side), 46 nets.

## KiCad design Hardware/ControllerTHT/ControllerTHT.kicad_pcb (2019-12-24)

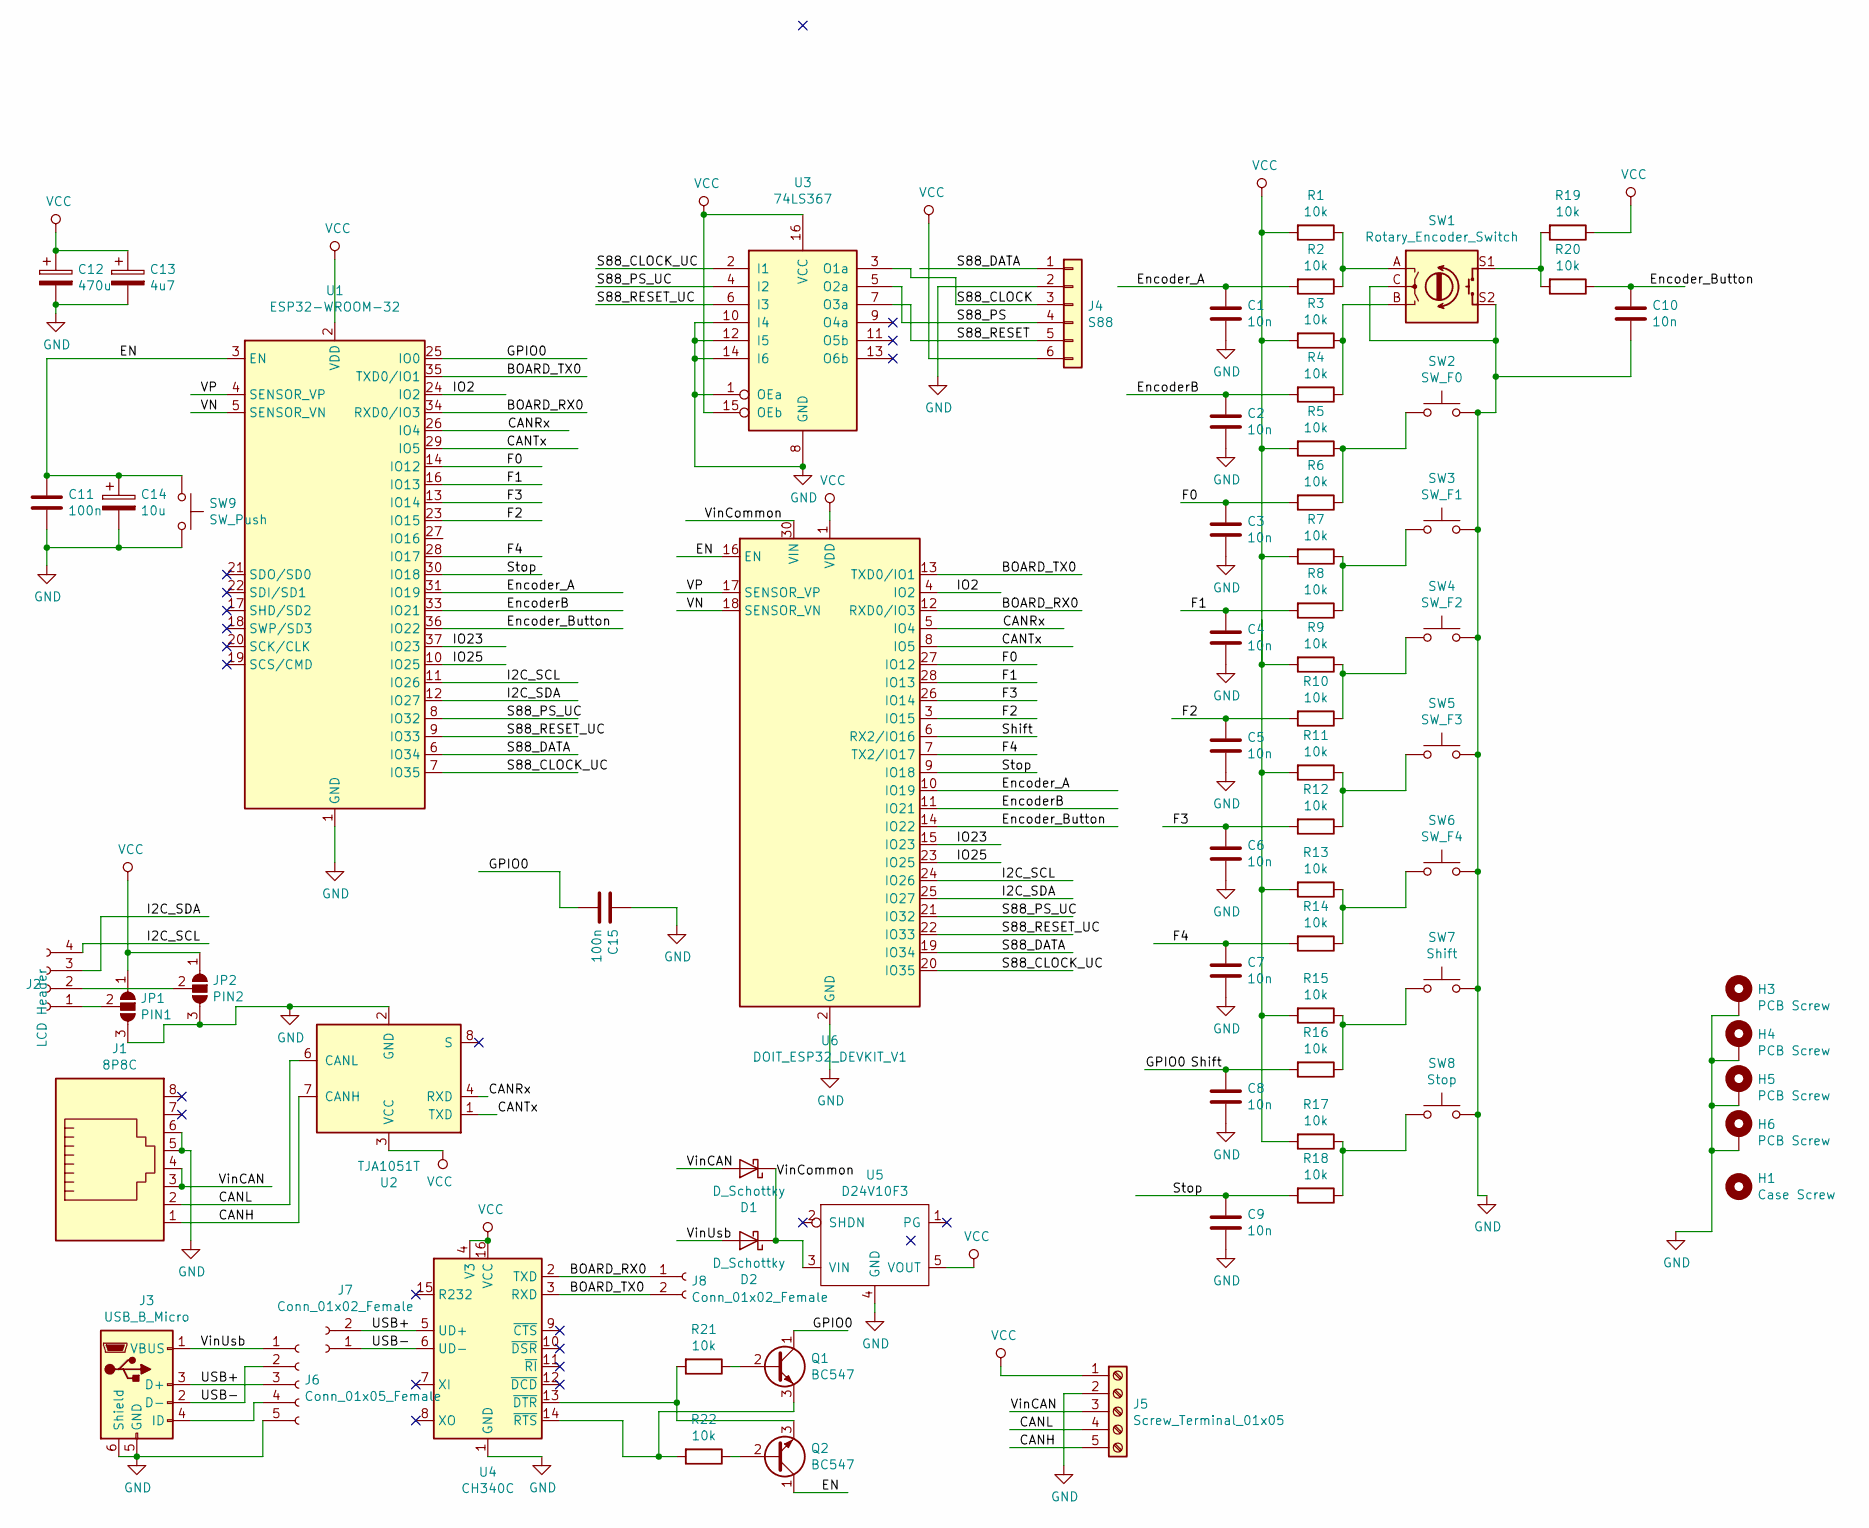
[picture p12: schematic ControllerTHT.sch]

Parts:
C1, C2, C3, C4, C5, C6, C7, C8, C9, C10: 10n; C_Disc_D3.4mm_W2.1mm_P2.50mm
C11, C15: 100n; C_Disc_D3.4mm_W2.1mm_P2.50mm
C12: 470u; CP_Radial_D10.0mm_P5.00mm
C13: 4u7; CP_Radial_D5.0mm_P2.50mm
C14: 10u; CP_Radial_D10.0mm_P5.00mm
D1, D2: D_Schottky; D_A-405_P7.62mm_Horizontal
H1: Case Screw; MountingHole_3.2mm_M3
H3, H4, H5, H6: PCB Screw; MountingHole_2.5mm_Pad_Via
J1: 8P8C; RJ45_Amphenol_54602-x08_Horizontal
J2: LCD Header; PinHeader_1x04_P2.54mm_Vertical
J3: USB_B_Micro; USB_Micro-B_Molex_47346-0001
J4: S88; PinHeader_1x06_P2.54mm_Horizontal
J5: Screw_Terminal_01x05; TerminalBlock_4Ucon_1x05_P3.50mm_Vertical
J6: Conn_01x05_Female; PinHeader_1x05_P2.54mm_Vertical
J7, J8: Conn_01x02_Female; PinHeader_1x02_P2.54mm_Vertical
JP1: PIN1; SolderJumper-3_P1.3mm_Open_Pad1.0x1.5mm_NumberLabels
JP2: PIN2; SolderJumper-3_P1.3mm_Open_Pad1.0x1.5mm_NumberLabels
Q1, Q2: BC547; TO-92_Inline
R1, R2, R3, R4, R5, R6, R7, R8, R9, R10, R11, R12, R13, R14, R15, R16, R17, R18, R19, R20, R21, R22: 10k; R_Axial_DIN0207_L6.3mm_D2.5mm_P10.16mm_Horizontal
SW1: Rotary_Encoder_Switch; RotaryEncoder_Alps_EC11E-Switch_Vertical_H20mm
SW2: SW_F0; SW_PUSH_6mm_H9.5mm
SW3: SW_F1; SW_PUSH_6mm_H9.5mm
SW4: SW_F2; SW_PUSH_6mm_H9.5mm
SW5: SW_F3; SW_PUSH_6mm_H9.5mm
SW6: SW_F4; SW_PUSH_6mm_H9.5mm
SW7: Shift; SW_PUSH_6mm_H9.5mm
SW8: Stop; SW_PUSH_6mm_H9.5mm
SW9: SW_Push; SW_PUSH_6mm
U1: ESP32-WROOM-32
U2: TJA1051T; SOIC-8_3.9x4.9mm_P1.27mm
U3: 74LS367; DIP-16_W7.62mm_Socket
U4: CH340C; SOIC-16_3.9x9.9mm_P1.27mm
U5: D24V10F3
U6: DOIT_ESP32_DEVKIT_V1; ESP32-DEVKITV1

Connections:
/BOARD_RX0: J8.1, U1.34 (RXD0/IO3), U4.2 (TXD), U6.12 (RXD0/IO3)
/BOARD_TX0: J8.2, U1.35 (TXD0/IO1), U4.3 (RXD), U6.13 (TXD0/IO1)
/CANH: J1.1, J5.5, U2.7 (CANH)
/CANL: J1.2, J5.4, U2.6 (CANL)
/CANRx: U1.26 (IO4), U2.4 (RXD), U6.5 (IO4)
/CANTx: U1.29 (IO5), U2.1 (TXD), U6.8 (IO5)
/EN: C11.1, C14.1, Q2.1 (C), SW9.1, U1.3 (EN), U6.16 (EN)
/EncoderB: C2.2, R4.2, U1.33 (IO21), U6.11 (IO21)
/Encoder_A: C1.2, R2.2, U1.31 (IO19), U6.10 (IO19)
/Encoder_Button: C10.2, R20.1, U1.36 (IO22), U6.14 (IO22)
/F0: C3.2, R6.2, U1.14 (IO12), U6.27 (IO12)
/F1: C4.2, R8.2, U1.16 (IO13), U6.28 (IO13)
/F2: C5.2, R10.2, U1.23 (IO15), U6.3 (IO15)
/F3: C6.2, R12.2, U1.13 (IO14), U6.26 (IO14)
/F4: C7.2, R14.2, U1.28 (IO17), U6.7 (TX2/IO17)
/GPIO0: C8.2, C15.2, Q1.1 (C), R16.2, U1.25 (IO0), U6.6 (RX2/IO16)
/I2C_SCL: J2.4, U1.11 (IO26), U6.24 (IO26)
/I2C_SDA: J2.3, U1.12 (IO27), U6.25 (IO27)
/IO2: U1.24 (IO2), U6.4 (IO2)
/IO23: U1.37 (IO23), U6.15 (IO23)
/IO25: U1.10 (IO25), U6.23 (IO25)
/S88_CLOCK: J4.3, U3.3 (O1a)
/S88_CLOCK_UC: U1.7 (IO35), U3.2 (I1), U6.20 (IO35)
/S88_DATA: J4.1, U1.6 (IO34), U6.19 (IO34)
/S88_PS: J4.4, U3.5 (O2a)
/S88_PS_UC: U1.8 (IO32), U3.4 (I2), U6.21 (IO32)
/S88_RESET: J4.5, U3.7 (O3a)
/S88_RESET_UC: U1.9 (IO33), U3.6 (I3), U6.22 (IO33)
/Stop: C9.2, R18.2, U1.30 (IO18), U6.9 (IO18)
/USB+: J3.3 (D+), J6.3, J7.2, U4.5 (UD+)
/USB-: J3.2 (D-), J6.2, J7.1, U4.6 (UD-)
/VN: U1.5 (SENSOR_VN), U6.18 (SENSOR_VN)
/VP: U1.4 (SENSOR_VP), U6.17 (SENSOR_VP)
/VinCAN: D1.2 (A), J1.3, J1.4, J5.3
/VinCommon: D1.1 (K), D2.1 (K), U5.3 (VIN), U6.30 (VIN)
/VinUsb: D2.2 (A), J3.1 (VBUS), J6.1
GND: C1.1, C2.1, C3.1, C4.1, C5.1, C6.1, C7.1, C8.1, C9.1, C10.1, C11.2, C12.2, C13.2, C14.2, C15.1, H3.1, H4.1, H5.1, H6.1, J1.5, J1.6, J3.5 (GND), J3.6 (Shield), J4.2, J5.2, J6.5, JP1.3 (B), JP2.3 (B), SW1.C, SW1.S2, SW2.2, SW3.2, SW4.2, SW5.2, SW6.2, SW7.2, SW8.2, SW9.2, U1.1 (GND), U1.15 (GND), U1.38 (GND), U2.2 (GND), U3.1 (OEa), U3.8 (GND), U3.10 (I4), U3.12 (I5), U3.14 (I6), U4.1 (GND), U5.4 (GND), U6.2 (GND), U6.29 (GND)
unnamed: J2.1, JP1.2 (C)
unnamed: J2.2, JP2.2 (C)
unnamed: J3.4 (ID), J6.4
unnamed: Q1.2 (B), R21.1
unnamed: Q1.3 (E), R22.2, U4.14 (~RTS)
unnamed: Q2.2 (B), R22.1
unnamed: Q2.3 (E), R21.2, U4.13 (~DTR)
unnamed: R1.1, R2.1, SW1.A
unnamed: R3.1, R4.1, SW1.B
unnamed: R5.1, R6.1, SW2.1
unnamed: R7.1, R8.1, SW3.1
unnamed: R9.1, R10.1, SW4.1
unnamed: R11.1, R12.1, SW5.1
unnamed: R13.1, R14.1, SW6.1
unnamed: R15.1, R16.1, SW7.1
unnamed: R17.1, R18.1, SW8.1
unnamed: R19.2, R20.2, SW1.S1
VCC: C12.1, C13.1, J4.6, J5.1, JP1.1 (A), JP2.1 (A), R1.2, R3.2, R5.2, R7.2, R9.2, R11.2, R13.2, R15.2, R17.2, R19.1, U1.2 (VDD), U2.3 (VCC), U3.15 (OEb), U3.16 (VCC), U4.4 (V3), U4.16 (VCC), U5.5 (VOUT), U6.1 (VDD)


Board: 2 copper layers, 71 parts (1 on the bottom side), 55 nets.

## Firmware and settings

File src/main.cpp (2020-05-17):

#include <Arduino.h>

#include "SPIFFS.h"

#include "config.h"

#include "hal/canManager.h"

#include <RR32Can/RR32Can.h>
#include "RR32Can/StationTxCbk.h"

#include "hal/ConsoleManager.h"
#include "hal/DisplayDriver.h"
#include "hal/Input.h"
#include "hal/storage/ActionListDB.h"
#include "hal/storage/Settings.h"
#include "hal/storage/TurnoutMap.h"
#include "hal/wifiManager.h"

#include "application/controller/MasterControl.h"

application::controller::MasterControl masterControl;

canManager canMgr;

ConsoleManager consoleMgr;

hal::DisplayDriver displayDriver;

application::model::Settings::CommunicationChannel_t activeCommunicationChannel;

hal::storage::Settings settingsStorage;
hal::storage::TurnoutMap turnoutMapStorage;
hal::storage::ActionListDB actionListStorage;

hal::Input input;

class TxCbk : public RR32Can::StationTxCbk {
  /**
   * \brief Send an arbitrary packet via CAN
   */
  void SendPacket(const RR32Can::Identifier& id, const RR32Can::Data& data) override {
    if (activeCommunicationChannel == application::model::Settings::CommunicationChannel_t::CAN &&
        canMgr.isActive()) {
      canMgr.SendPacket(id, data);
    } else if (activeCommunicationChannel ==
                   application::model::Settings::CommunicationChannel_t::WIFI &&
               isWifiAvailable()) {
      WiFiSendPacket(id, data);
    } else {
      printf("No active communication channels available.\n");
    }
  }
};

TxCbk txCbk;

void activateCommunicationChannel(application::model::Settings::CommunicationChannel_t channel);

void setup() {
  // Start serial and wait for its initialization
  consoleMgr.initialize_console();

  printf("\n###################\nCAN Turnout Control\n###################\n");

  // Open SPIFFS to be able to store settings
  if (SPIFFS.begin(true)) {
    printf("SPIFFS mount succeeded.\n");
  } else {
    printf("SPIFFS mount failed.\n");
  }

  masterControl.begin(settingsStorage, turnoutMapStorage, actionListStorage);
  displayDriver.begin();
  input.begin(masterControl.getInputState());

  const application::model::Settings& userSettings = masterControl.getUserSettings();

  canMgr.begin();
  setupWifi();

  activeCommunicationChannel = userSettings.communicationChannel;
  activateCommunicationChannel(userSettings.communicationChannel);

  RR32Can::RR32Can.begin(RR32CanUUID, masterControl, txCbk);

  consoleMgr.setupCommands(masterControl.getActionListModel(),
                           masterControl.getActionListProcessor(), actionListStorage);

  consoleMgr.StartTask();
}

void loop() {
  RR32Can::RR32Can.loop();

  input.loop();

  masterControl.loop();

  WifiInputLoop();

  canMgr.loop();

  application::model::Settings::CommunicationChannel_t newChannel =
      masterControl.getUserSettings().communicationChannel;

  if (activeCommunicationChannel != newChannel) {
    activateCommunicationChannel(newChannel);
    activeCommunicationChannel = newChannel;
  }

  auto& displayModel = masterControl.getDisplayModel();
  displayModel.setCan(canMgr.isActive());
  displayModel.setWifi(isWifiAvailable());
  displayDriver.loop(displayModel);
}

void activateCommunicationChannel(application::model::Settings::CommunicationChannel_t channel) {
  switch (channel) {
    case application::model::Settings::CommunicationChannel_t::CAN:
      stopWifi();
      canMgr.startCan();
      break;

    case application::model::Settings::CommunicationChannel_t::WIFI:
      canMgr.stopCan();
      startWifi();
      break;
  }
}

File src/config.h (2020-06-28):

#ifndef __CONFIG_H__
#define __CONFIG_H__

#include <cstdint>
#include "RR32Can/Constants.h"
#include "RR32Can_config.h"

// Use 0 for "manual settings", 1 for first prototype, 2 for second prototype, 3 for control only
#define HARDWARE_VERSION (1)

#ifndef HARDWARE_VERSION
#error "You must set a Hardware verison. Use 0 if unsure."
#endif

/*
 * Configuration of attached hardware
 */

#define DISPLAY_ATTACHED STD_ON
#define ENCODER_ENABLED STD_ON

#define S88_DATA_IN_PIN (18)
#define S88_CLOCK_OUT_PIN (23)
#define S88_PS_OUT_PIN (22)
#define S88_RESET_OUT_PIN (21)

#define CAN_DRIVER_SJA1000 STD_OFF
#define CAN_DRIVER_ESP32IDF STD_ON

#if (CAN_DRIVER_SJA1000 == STD_ON) && (CAN_DRIVER_ESP32IDF == STD_ON)
#error Only one CAN driver can be active at any time.
#endif

// CAN pins use default driver values
#if CAN_DRIVER_SJA1000 == STD_ON
#define CAN_RX_PIN (4)
#define CAN_TX_PIN (5)
#else
#define CAN_RX_PIN (GPIO_NUM_4)
#define CAN_TX_PIN (GPIO_NUM_5)
#endif

#if (HARDWARE_VERSION == 1 || HARDWARE_VERSION == 2)
#define TWI_SCL_PIN (26)
#define TWI_SDA_PIN (27)
#elif (HARDWARE_VERSION == 3)
#define TWI_SCL_PIN (25)
#define TWI_SDA_PIN (26)
#endif

#if (DISPLAY_ATTACHED == STD_ON)
#define DISPLAY_TWI_ADDRESS (0x3C)

#if (HARDWARE_VERSION == 1 || HARDWARE_VERSION == 2)
#define DISPLAY_FLIP_SCREEN STD_OFF
#elif (HARDWARE_VERSION == 3)
#define DISPLAY_FLIP_SCREEN STD_ON
#endif

#define DISPLAY_CONTROLLER_SH1106 (1)
#define DISPLAY_CONTROLLER_SSD1306 (2)

#if (HARDWARE_VERSION == 1 || HARDWARE_VERSION == 3)
#define DISPLAY_CONTROLLER_TYPE DISPLAY_CONTROLLER_SSD1306
#elif (HARDWARE_VERSION == 2)
#define DISPLAY_CONTROLLER_TYPE DISPLAY_CONTROLLER_SH1106
#else
// Set manually here
#define DISPLAY_CONTROLLER_TYPE DISPLAY_CONTROLLER_SSD1306
#endif

#ifndef DISPLAY_CONTROLLER_TYPE
#error "Please define a display controller type"
#endif
#endif  // DISPLAY_ATTACHED

/*
 * Configuration of input buttons
 */

#if (ENCODER_ENABLED == STD_ON)
#if (HARDWARE_VERSION == 1 || HARDWARE_VERSION == 2)
#define ENCODER_A_PIN (35)
#define ENCODER_B_PIN (32)
#elif (HARDWARE_VERSION == 3)
#define ENCODER_A_PIN (18)
#define ENCODER_B_PIN (23)
#endif

#define NUM_FBUTTONS (5)
#endif  // ENCODER_ENABLED

#if (HARDWARE_VERSION == 1)
#define SHIFT_REGISTER_LENGTH (48U)
#define TURNOUT_BUTTONS_OFFSET (8)
#define TURNOUT_BUTTONS_COUNT (SHIFT_REGISTER_LENGTH - TURNOUT_BUTTONS_OFFSET)
#elif (HARDWARE_VERSION == 2)
#define SHIFT_REGISTER_LENGTH (64U)
#define TURNOUT_BUTTONS_OFFSET (8)
#define TURNOUT_BUTTONS_COUNT (SHIFT_REGISTER_LENGTH - TURNOUT_BUTTONS_OFFSET)
#elif (HARDWARE_VERSION == 3)
#define SHIFT_REGISTER_LENGTH (0U)
#define TURNOUT_BUTTONS_OFFSET (0)
#define TURNOUT_BUTTONS_COUNT (0U)
#else
// Set manually here
#define SHIFT_REGISTER_LENGTH (64U)
#define TURNOUT_BUTTONS_OFFSET (8)
#define TURNOUT_BUTTONS_COUNT (SHIFT_REGISTER_LENGTH - TURNOUT_BUTTONS_OFFSET)
#endif

/*
 * Buttons are:
 * Encoder
 * Shift
 * Stop
 * Function Keys
 *
 * They can be mapped to a GPIO or to a shift register bit or not be mapped at all.
 * Typically they are all mapped to GPIOs or all to shift registers.
 *
 * Make sure to set TURNOUT_BUTTONS_OFFSET accordingly!
 */
#define KEY_MODE_SHIFTREGISTER (1)
#define KEY_MODE_GPIO (2)

#if (HARDWARE_VERSION == 1 || HARDWARE_VERSION == 2)
#define FUNCTION_KEY_MODE KEY_MODE_SHIFTREGISTER
#elif (HARDWARE_VERION == 3)
#define FUNCTION_KEY_MODE KEY_MODE_GPIO
#else
// Define your own
#define FUNCTION_KEY_MODE KEY_MODE_GPIO
#endif

#if (FUNCTION_KEY_MODE == KEY_MODE_SHIFTREGISTER)
#define KEY_BIT_ENCODER (7)
#define KEY_BIT_SHIFT (5)
#define KEY_BIT_STOP (6)
#define KEY_BIT_F_OFFSET (0)
#define KEY_BIT_F_COUNT (NUM_FBUTTONS)
#endif

#if (FUNCTION_KEY_MODE == KEY_MODE_GPIO)
#define KEY_GPIO_ENCODER (16)
#define KEY_GPIO_SHIFT (04)
#define KEY_GPIO_STOP (0)
#define KEY_GPIO_F0 (22)
#define KEY_GPIO_F1 (05)
#define KEY_GPIO_F2 (15)
#define KEY_GPIO_F3 (21)
#define KEY_GPIO_F4 (17)
#endif

#if (SHIFT_REGISTER_LENGTH < NUM_TURNOUT_BITS)
#error "Shift Register is too short."
#endif

// Debouncing on is not tested
#define KEYS_DEBOUNCE STD_OFF
#define LOG_KEYS_DEBOUNCE STD_OFF

static constexpr const uint8_t kActionListMaxLength = 6;

#endif  // __CONFIG_H__

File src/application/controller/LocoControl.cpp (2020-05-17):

#include "application/controller/LocoControl.h"
#include <application/controller/MasterControl.h>

#include "RR32Can/RR32Can.h"
#include "application/view/UIAssets.h"

namespace application {
namespace controller {

void LocoControl::begin() { loco.reset(); }

void LocoControl::loop(application::model::InputState& inputState, MasterControl& masterControl) {
  // Check Encoder button
  if (inputState.isEncoderRisingEdge()) {
    if (inputState.isShiftPressed()) {
      // switch to locolist on shift+encoder
      masterControl.enterLocoList();
    } else {
      // Encoder pressed
      if (loco.isFullDetailsKnown()) {
        // Send emergency stop for engine
        RR32Can::RR32Can.SendEmergencyStop(loco);
        // Send direction reverse for engine
        RR32Can::RR32Can.SendEngineDirection(loco, switchDirection(loco.getDirection()));
      }
    }
  }

  if (loco.isFullDetailsKnown()) {
    // Check function keys
    application::model::InputState::FunctionKeyArray_t& functionKeys = inputState.getFunctionKeys();

    for (uint8_t i = 0; i < NUM_FBUTTONS; ++i) {
      if (functionKeys[i].getAndResetRisingEdge()) {
        // Always get and reset the edge
        uint8_t functionNum = i;
        if (i > 0 && inputState.isShiftPressed()) {
          // Note: F0 is not shifted
          functionNum += NUM_FBUTTONS - 1;
        }
        bool functionStatus = loco.getFunction(functionNum);
        RR32Can::RR32Can.SendEngineFunction(loco, functionNum, !functionStatus);
      }
    }

    // Check encoder
    checkEncoder(inputState);
  }
}

void LocoControl::checkEncoder(application::model::InputState& inputState) {
  application::model::InputState::EncoderPosition_t encoderPosition =
      inputState.encoder.getPosition();

  // See if there was an effective change to the reported encoder position
  if (inputState.lastEncoderState.position != encoderPosition) {
    inputState.lastEncoderState.position = encoderPosition;

    /* Limit newPosition to 0..kMaxEngineVelocity and reset the encoder
     appropriately, if necessary. */
    if (encoderPosition < 0) {
      encoderPosition = 0;
      inputState.loadEncoderPosition(encoderPosition);
    } else if (encoderPosition > RR32Can::kMaxEngineVelocity) {
      encoderPosition = RR32Can::kMaxEngineVelocity;
      inputState.loadEncoderPosition(encoderPosition);
    } else {
      // Encoder moved in bounds

      // evaluate acceleration...
      RotaryEncoder::Direction currentDirection = inputState.encoder.getDirection();
      if (currentDirection == inputState.lastEncoderState.direction &&
          currentDirection != RotaryEncoder::Direction::NOROTATION &&
          inputState.lastEncoderState.direction != RotaryEncoder::Direction::NOROTATION) {
        // ... but only of the direction of rotation matched and there
        // actually was a previous rotation.
        unsigned long deltat = inputState.encoder.getMillisBetweenRotations();

        // at 500ms, there should be no acceleration.
        constexpr const unsigned long kAccelerationLongCutoffMillis = 500;
        if (deltat < kAccelerationLongCutoffMillis) {
          constexpr const unsigned long kAccelerationShortCutffMillis = 4;  // 50/12
          if (deltat < kAccelerationShortCutffMillis) {
            // limit to maximum acceleration
            deltat = kAccelerationShortCutffMillis;
          }

          constexpr static const float m = -0.16;
          constexpr static const float c = 84.03;

          float ticksActual_float = m * deltat + c;
          // Round by adding 1
          // Then again remove 1 to determine the actual delta to the encoder
          // value, as the encoder already ticked by 1 tick in the correct
          // direction Thus, just cast to integer.
          long deltaTicks = (long)ticksActual_float;

          // Adjust sign: Needs to be inverted for counterclockwise operation
          if (currentDirection == RotaryEncoder::Direction::COUNTERCLOCKWISE) {
            deltaTicks = -(deltaTicks);
          }

          long newEncoderPosition = encoderPosition + deltaTicks;
          if (newEncoderPosition > RR32Can::kMaxEngineVelocity) {
            newEncoderPosition = RR32Can::kMaxEngineVelocity;
          } else if (newEncoderPosition < 0) {
            newEncoderPosition = 0;
          }

          encoderPosition = newEncoderPosition;
          inputState.loadEncoderPosition(newEncoderPosition);
        }
      } else {
        inputState.lastEncoderState.direction = currentDirection;
      }

      // Update the engine velocity

      if (loco.isFullDetailsKnown()) {
        RR32Can::Locomotive::Velocity_t oldVelocity = loco.getVelocity();
        if (encoderPosition != oldVelocity) {
          RR32Can::RR32Can.SendEngineVelocity(loco, encoderPosition);
        }
      }
    }
  }
}

void LocoControl::reset() { loco.reset(); }

bool LocoControl::setLocoInfo(const RR32Can::LocomotiveShortInfo& locoInfo) {
  if (strncmp(loco.getName(), locoInfo.getName(), RR32Can::kEngineNameLength) == 0) {
    return false;
  } else {
    loco.reset();
    loco.setName(locoInfo.getName());
    return true;
  }
}

void LocoControl::updateDisplayOnce(application::model::DisplayModel& displayManager) {
  {
    constexpr static const uint8_t nameLengthLimit =
        (STRING_CHAR_LENGTH > RR32Can::kEngineNameLength ? STRING_CHAR_LENGTH
                                                         : RR32Can::kEngineNameLength);

    strncpy(displayManager.getWritableBuffer(0), loco.getName(), nameLengthLimit);
    displayManager.disableCursor();
  }

  if (loco.isFullDetailsKnown()) {
    char* buf = displayManager.getWritableBuffer(1);

    const char* protocolString = loco.getProtocolString();
    RR32Can::Locomotive::Address_t address = loco.getAddress();

    snprintf(buf, STRING_CHAR_LENGTH, "%s %i", protocolString, address);

  } else {
    strncpy(displayManager.getWritableBuffer(1), application::view::kFetching, STRING_CHAR_LENGTH);
  }
}

void LocoControl::updateDisplayLoop(application::model::DisplayModel& displayManager) {
  if (loco.isFullDetailsKnown()) {
    displayManager.setDirection(loco.getDirection());
    displayManager.setSpeedValue(map(loco.getVelocity(), 0, RR32Can::kMaxEngineVelocity, 0, 100));
    displayManager.setFunctionBits(loco.getFunctionBits());
  } else {
    displayManager.setDirection(RR32Can::EngineDirection::UNKNOWN);
    displayManager.setSpeedValue(0);
    displayManager.setFunctionBits(0u);
  }
}

void LocoControl::setReceivedVelocity(RR32Can::Velocity_t velocity, MasterControl& uiControl) {
  loco.setVelocity(velocity);
  if (uiControl.getUIMode() == MasterControl::UIMode::LOCOCONTROL) {
    application::model::InputState& inputState = uiControl.getInputState();
    if (velocity != inputState.encoder.getPosition()) {
      inputState.encoder.setPosition(velocity);
    }
  }
}
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

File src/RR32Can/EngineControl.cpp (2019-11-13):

#include "RR32Can/EngineControl.h"

#include <Arduino.h>

#include "config.h"

#include "RR32Can/RR32Can.h"

namespace RR32Can {

const char* EngineControl::kFilenameEngine = "lokinfo";
const char* EngineControl::kFilenameEngineResult = "lokomotive";
const char* EngineControl::kEngineKeyUid = "uid";
const char* EngineControl::kEngineKeyVelocity = "velocity";
const char* EngineControl::kEngineKeyDirection = "richtung";
const char* EngineControl::kEngineKeyProtocol = "typ";
const char* EngineControl::kEngineKeyAddress = "adresse";

const char* EngineControl::kNoEngineSelected = "- No Engine -";

void EngineControl::consumeConfigData(BufferManager& section,
                                      BufferManager& key,
                                      BufferManager& value) {
#if (LOG_CONFIG_DATA_STREAM_LEVEL >= LOG_CONFIG_DATA_STREAM_LEVEL_EVENTS)
  Serial.print("EngineControl::consumeConfigData(");
  Serial.print(section.data());
  Serial.print(", ");
  Serial.print(key.data());
  Serial.print(", ");
  Serial.print(value.data());
  Serial.println(");");
#endif

  if (currentEngine == nullptr) {
    return;
  }

  if (strncmp(kFilenameEngineResult, section.data(), section.length()) == 0) {
    /* It is a lokomotive */
    if (strncmp(kEngineKeyUid, key.data(), key.length()) == 0) {
      // UID
      currentEngine->setUid(strtoul(value.data(), NULL, 16));
#if (LOG_CONFIG_DATA_STREAM_LEVEL >= LOG_CONFIG_DATA_STREAM_LEVEL_EVENTS)
      printf("Setting UID\n");
#endif

    } else if (strncmp(kEngineKeyProtocol, key.data(), key.length()) == 0) {
      currentEngine->setProtocolString(value.data());
#if (LOG_CONFIG_DATA_STREAM_LEVEL >= LOG_CONFIG_DATA_STREAM_LEVEL_EVENTS)
      printf("Setting protocol\n");
#endif
    } else if (strncmp(kEngineKeyAddress, key.data(), key.length()) == 0) {
      currentEngine->setAddress(strtoul(value.data(), NULL, 16));
#if (LOG_CONFIG_DATA_STREAM_LEVEL >= LOG_CONFIG_DATA_STREAM_LEVEL_EVENTS)
      printf("Setting Address\n");
#endif
    } /* else: Unused data item. */
  }
}

void EngineControl::setStreamComplete() {
  if (currentEngine == nullptr) {
    return;
  }

  currentEngine->availability = Engine::AvailabilityStatus::FULL_DETAILS;

  Serial.print("Downloaded Engine: ");
  currentEngine->print();
  Serial.println();
}

void EngineControl::setStreamAborted(){};

}  // namespace RR32Can

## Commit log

2018-12-30 Import of initial working prototype
2019-02-13 Display the Encoder value
2019-02-15 Moved sending CAN frames to the handler file
2019-02-16 Initial PCB
    An initial take at a PCB that can be mounted in the SP 2092 case.
    NOTE: The dimensions do not yet match!
    [Controller.kicad_pcb, Controller.sch]
2019-02-17 Updated fitting for SP 2090 enclosure
    Better fit, but still not perfect.
    [Controller.kicad_pcb, Controller.sch]
2019-02-17 Finished case-specific layout parts
    [Controller.kicad_pcb]
2019-02-17 Added a first set of parts
    [Controller.kicad_pcb, Controller.sch]
2019-02-20 Added more parts
    [Controller.kicad_pcb, Controller.sch]
2019-02-21 Added initial TextParser and a CMake configuration for UnitTesting
    * Downloads Google Test
    * Compiles selected sources and enables unit testing
    * Adapted apply-clang.sh to also format test case implementations
    * Initial set of bugfixes
2019-02-23 Rename project to avoid Copyright problems
    [EngineControl.cpp, config.h, main.cpp]
2019-02-23 Added Text parsing of incoming configuration data
    Configuration data is received and parsed. Currently, the identified tokens are dumped to the serial console only.
2019-03-04 Added XM1548 and worked on Hardware
    [Controller.kicad_pcb, Controller.sch]
2019-03-05 Switched to all-SMD Buttons
    [Controller.kicad_pcb, Controller.sch]
2019-03-08 Finished PCB
    * Reordered some pins to make the PCB layout easier
    * Added connector descriptions
    * Adjusted Silkscreen Items
    [Controller.kicad_pcb, Controller.sch]
2019-03-10 Updated USB Port
    [Controller.kicad_pcb, Controller.sch]
2019-03-12 Optimizations
    * Moved Screen connector to the other side
    * Optimized knee bends
    [Controller.kicad_pcb, Controller.sch]
2019-03-16 Fixed part footprints
    [Controller.kicad_pcb, Controller.sch]
2019-03-16 Fixes for Manufacturing
    [Controller.kicad_pcb, Controller.sch]
2019-05-19 Swap RX/TX
    Fixes #1
    [Controller.kicad_pcb, Controller.sch]
2019-05-26 Moved SMD controller prototype to separate folder
    [Controller.kicad_pcb, Controller.sch]
2019-05-26 Initial version of THT controller
    [ControllerTHT.kicad_pcb, ControllerTHT.sch]
2019-05-26 Bare PCB for Bopla BS 403
    [ControllerTHT.kicad_pcb]
2019-05-26 More tinkering with Footprints
    [ControllerTHT.kicad_pcb, ControllerTHT.sch]
2019-05-30 Intermediate steps
    [ControllerTHT.kicad_pcb, ControllerTHT.sch]
2019-05-30 Added an experimental ESP32 Breakout Board for Prototyping
    [ESP32Breakout.kicad_pcb, ESP32Breakout.sch]
2019-05-30 Fixup of holes and labels
    [ESP32Breakout.kicad_pcb, ESP32Breakout.sch]
2019-05-30 Add IO Breakout PCB
    [IOBreakout.kicad_pcb, IOBreakout.sch]
2019-11-01 Added switch for Display Flip
    [config.h]
2019-11-01 Switch menu when shift is pressed
2019-11-02 Added option to conditionally set the name of the engine
    Avoids loosing the engine state in case the current engine was reselected.
2019-11-03 Fix scrolling through the engine list
    [EngineControl.cpp]
2019-11-03 Fixed requesting the correct engine
    [EngineControl.cpp]
2019-11-05 Switch to ESP32-IDF CAN driver.
    This driver allows better buffer control.
2019-11-07 Track engine speed & direction.
    Requests engine speed and direction when a new engine is selected. Updates display when another bus participant controls the engine.
2019-11-10 Added Acceleration for the encoder in Engine Control mode.
    Actual acceleration values may require additional tweaking.
2019-11-24 WIP: Added runtime-modifiable button map
2019-11-24 Runtime-remapping of buttons now works
2019-11-30 Iniitalize Turnout buttons to inverted state.
    Fixes #4.
2019-11-30 Fix engine speed not being recoreded correctly on emergency stop
    [LocoControl.cpp]
2019-12-01 Resolve off-by-one in turnout mapping.
    [TurnoutMenu.cpp]
2019-12-01 Improve computation of turnout buttons
2019-12-01 Force all stored mappings to be SingleTurnout.
    ActionLists are currently not supported.
2019-12-01 Added a function to print turnout mappging entries
2019-12-07 Added easy switch for multiple hardware confguations
2019-12-15 Added switching turnouts via serial
2019-12-16 Fix prints and includes
    [Input.cpp]
2019-12-22 Serialized Aciton Lists during printout
2019-12-24 Updated all boards
    ESP32Breakout now with S88 driver.
    ESP32Breakout has the auto-reset circut removed.
    [Controller.kicad_pcb, Controller.sch, ControllerTHT.kicad_pcb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]
2019-12-27 Added a PCB for an S88 switchboard.
    [Switchboard.kicad_pcb, Switchboard.sch]
2019-12-27 Fixed positioning of switches
    [Switchboard.kicad_pcb]
2019-12-27 More position fixes.
    [Switchboard.kicad_pcb]
2019-12-27 Converted mounting holes to vias
    [Switchboard.kicad_pcb, Switchboard.sch]
2019-12-28 Added smaller SMD version of switchboard
    [SwitchboardSMD.kicad_pcb, SwitchboardSMD.sch]
2019-12-28 Added a Breakout for an HCT367
    [S88Driver.kicad_pcb, S88Driver.sch]
2019-12-29 Fixes on the breakout board
    [ESP32Breakout.kicad_pcb]
2019-12-29 Added gerber folders to gitignore
2019-12-29 Updates projects for manufacturing
    [S88Driver.kicad_pcb, SwitchboardConnector.kicad_pcb, SwitchboardConnector.sch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]
2019-12-29 Further updates
    [S88Driver.kicad_pcb, S88Driver.sch, SwitchboardConnector.kicad_pcb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]
2019-12-29 Fixed IC footprints
    [SwitchboardSMD.kicad_pcb, SwitchboardSMD.sch]
2019-12-29 Move to printf and update formatting
2020-01-01 Added LocoCard Breakout
    [LocoCardBreakout.kicad_pcb, LocoCardBreakout.sch]
2020-01-07 Rounded Corners
    [ESP32Breakout.kicad_pcb]
2020-05-16 Switch from Ninja to make
2020-05-16 Switched to GCC8
2020-05-16 Switched to Clang9
2020-05-17 Added better input button mapping.
    Let Can driver be disabled altogether.
2020-05-17 Some fixes to GPIO-based input
    [Input.cpp]
2020-05-17 Fixed Pin assignment
2020-06-21 Fixed inverted power connections for shift register
    [SwitchboardSMD.kicad_pcb, SwitchboardSMD.sch]
2020-06-21 Fixed silkscreen
    [SwitchboardSMD.kicad_pcb]
2025-08-28 Updated to v1.3 for manufacturing
    [SwitchboardSMD.kicad_pcb, SwitchboardSMD.kicad_sch]
2025-08-28 Updated Geometry
    [SwitchboardSMD.kicad_pcb, SwitchboardSMD.kicad_sch]
2025-08-28 Fix VCC/GND assignment
    [SwitchboardSMD.kicad_pcb, SwitchboardSMD.kicad_sch]
2025-08-28 Updated JLCPCB DRC
    [SwitchboardSMD.kicad_pcb]
2025-08-28 Center connectors
    [SwitchboardSMD.kicad_pcb]
2025-08-28 Added Production Files
    [BOM-SwitchboardSMD.csv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]
2025-08-30 Updated production files
    [BOM-SwitchboardSMD.csv, SwitchboardSMD.kicad_pcb, SwitchboardSMD.kicad_sch]
2025-08-31 Files as sent for production
    [BOM-SwitchboardSMD.csv, SwitchboardSMD.kicad_pcb, SwitchboardSMD.kicad_sch]
